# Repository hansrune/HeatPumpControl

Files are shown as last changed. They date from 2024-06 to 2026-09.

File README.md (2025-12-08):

# Generic ESP32 C3/C6 board with IR blaster, serial port, i2c, 1-wire and more

A small DYI generic mini IO based on ESP32C3 or ESP32C6 from Xiaomi SeeedStudio. This board has an IR blaster, IR receiver, and serial port with a simple 5V - 3.3V level shifter suitable for Mitsubishi CN105 port (similar for any RS-232 interfaces) . Other ESP32 pins are available with pin headers for I2C, 1-wire, and other general purposes

This board is tested with ESPhome and ESPEasy [firmware](#firmwares) (build instructions below), and is easily used with home automation systems that support MQTT auto discovery, the native Home Assistant API, and the many [controllers that ESPEasy supports](https://espeasy.readthedocs.io/en/latest/Controller/_Controller.html)

A [3D printed box](#./FreeCAD/) STL files and  the FreeCAD design is also available

**PLEASE NOTE**: Use at your own risk. The ESPhome firmwares are unofficial and reverse-engineered Mitsubishi protocol based on the [Swicago library](https://github.com/SwiCago/HeatPump). The authors and contributors have extensively tested this firmware. Please note that not all units support every feature. If you need an officially supported method to remotely control your Mitsubishi device via WiFi, a commercial solution is available [here](https://www.mitsubishi-electric.co.nz/wifi/)

## Introduction

This small IO board was made to easily fit inside a small DYI box, a heat pump or other.

For Mitsubushi heat pumps, the CN105 connector is used for serial port communications and for power supply.

Some of the main features and benefits

- **Serial port with simple level shifter for 5V serial ports**
    - The CN105 port of Mitsubishi ports can be used - and will then also provide the power supply for the board
- **An IR blaster circuit**
    - Some features / command packets are easier to find from a native IR receiver
- **I2C and/or 1-wire**
- **Other GPIO ports**
- **WiFi based**
    - This is almost a must have for most home automation systems
    - OTA support
    - Configuration backup, restore and bulk updates.
- **Firmware of your choise**
    - ESPEasy with Domoticz over http. Device creation uses virtual sensors
    - ESPEasy with Domoticz and Home Assistant via MQTT. Device creation uses a MQTT configuration text file.
    - ESPHome to Home Assistant via MQTT and auto discovery
    - ESPHome to Domoticz via MQTT and auto discovery
    - ... and as the hardware supports using both Arduino and ESP-IF development kits, almost any other firmware can be created.
- **3D printed enclosure**
    - [FreeCAD](./FreeCAD) and `.stl` files provided
- **Seed Studio XIAO ESP32C3**
    - This device is well shielded and comes with an externam IPX antenna connector
    - FCC and CE regulations approved

### Heat pump wiring

The wiring for a Mistubishi heat pump:

<p align="center">
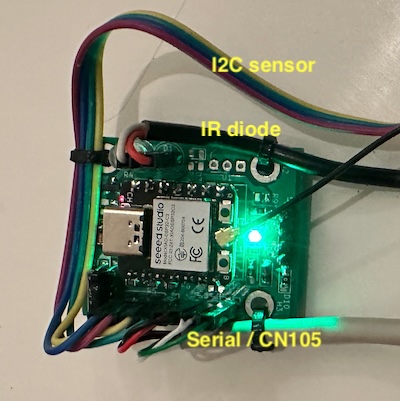
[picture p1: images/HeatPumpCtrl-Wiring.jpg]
    
</p>

A visible LED can be used in series with the IR LED - just in case you want to see the activity

The serial port - CN105 - on our Mitsubishi heat pumps:

<p align="center">
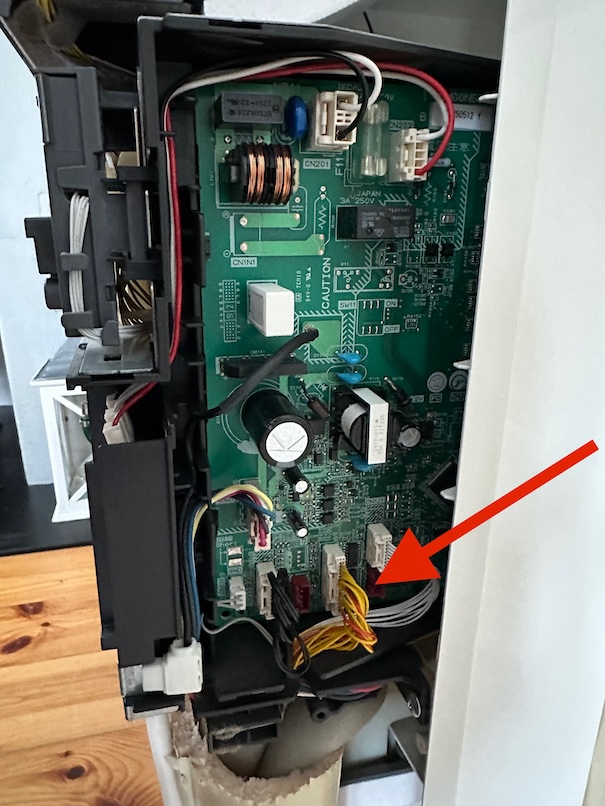
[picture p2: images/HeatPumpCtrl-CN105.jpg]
    
</p>

The IR sender led fits inside the receiver housing:

<p align="center">
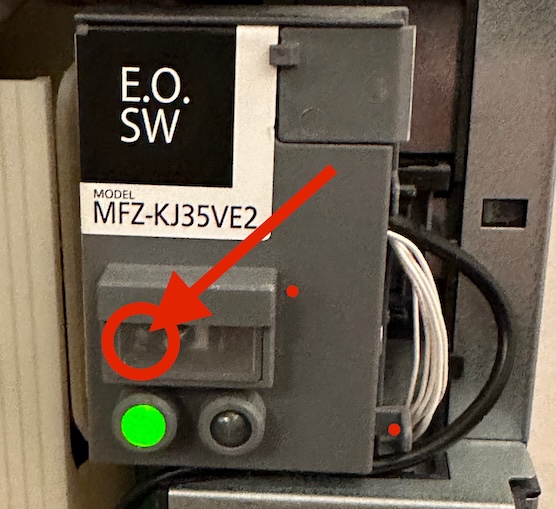
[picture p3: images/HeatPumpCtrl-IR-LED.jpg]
    
</p>

And the device including enclosure is tiny, i.e. easy to find room for inside the heat pump:

<p align="center">
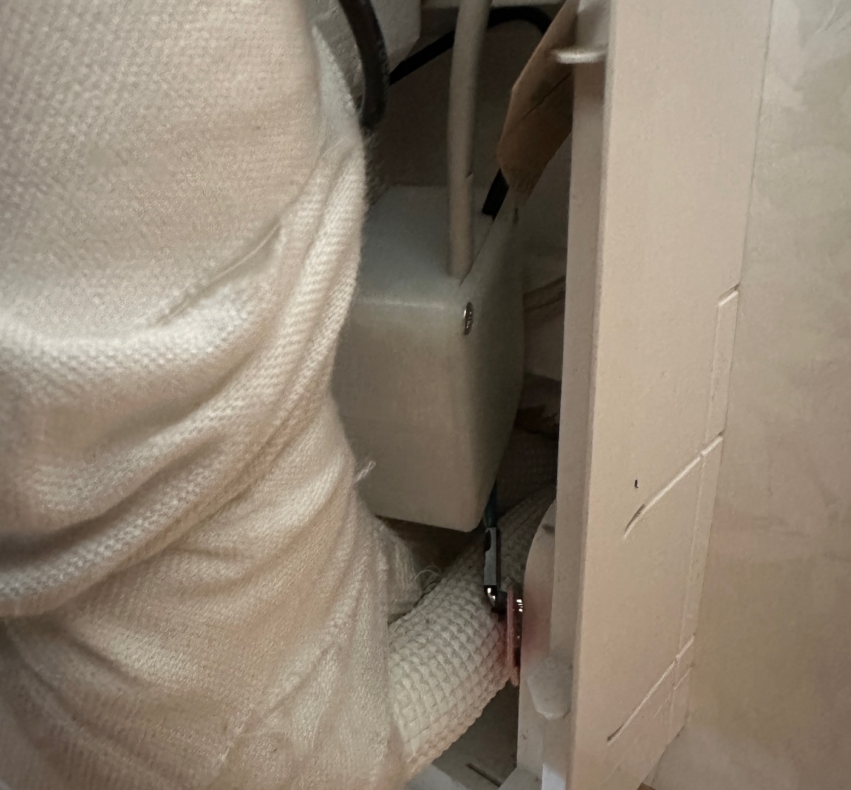
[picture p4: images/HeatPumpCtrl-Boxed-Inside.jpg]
    
</p>

### Wiring for other purposes

The same PCB can be used for many other purposes. Here is for a firmware build test with CO2 sensor, I2C temp/humid and light, PIR sensor and a 1-wire temp sensor

<p align="center">
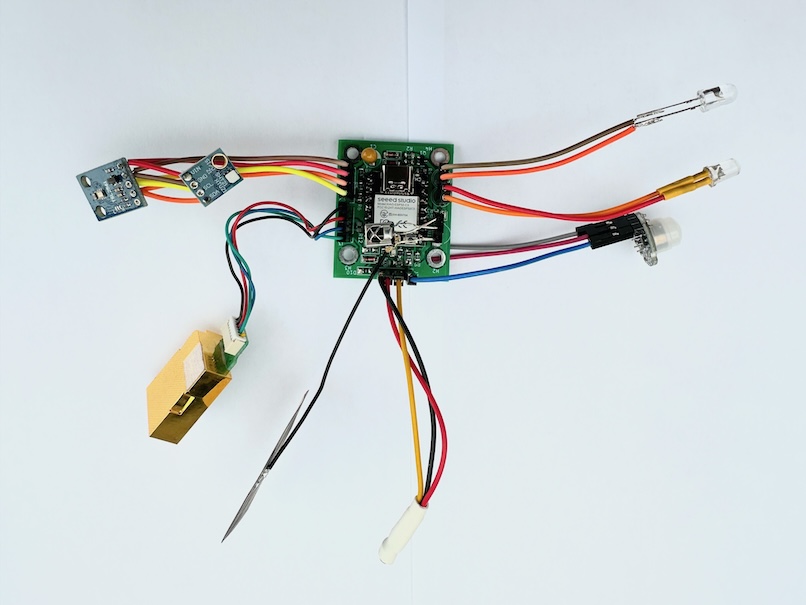
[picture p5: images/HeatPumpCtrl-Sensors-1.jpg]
    
</p>

## Implementation and design

The schematic diagram is [available here](KiCad/HeatPumpControl-schema-2.0.pdf). The [KiCad EDA](https://www.kicad.org/) project is in the [same folder](./KiCad)

## GPIO pin usage

| PIN | Capabilty | Function |
|---|---|---|
| GPIO2 | Pulled up | N/A |
| GPIO3/A1 | Generic IO | On IR receiver pin header |
| GPIO4 | Actice high out | IR sender |
| GPIO5 | Generic IO | Pull-up possible |
| GPIO6 | I2C | SDA |
| GPIO7 | I2C | SCL |
| GPIO9 | Active low out | Internal status LED |
| GPIO10 | Generic IO | Pull-up possible |
| GPIO20 | RX | Serial to heatpump TX |
| GPIO21 | TX | Serial to heatpump RX |

## Hardware - getting started

This project uses my [KiCad-lib-ESP32 repository](https://github.com/hansrune/KiCad-lib-ESP32.git) as a [git submodule](https://www.git-scm.com/book/en/v2/Git-Tools-Submodules). To check this out, use the following:

```bash
git clone --recurse-submodules https://github.com/hansrune/HeatPumpControl.git 
```

### Materials used

This project uses the [Seed Studio XIAO ESP32C3 RISC-V module](https://www.seeedstudio.com/Seeed-XIAO-ESP32C3-p-5431.html). This tiny device has proven to be more reliable than most ESP8266 modules. This module also comes with an IPX connector for an external antenna, and is delivered with a simple external antenna for good range.

5V power can be supplied over USB-C or the serial port pin headers

For more information, use [this KiCad BOM](KiCad/HeatPumpControl-BOM.csv)

## Hardware assembly

Soldering a prototype by hand is possible if you have a steady hand and a small solder iron tip. A microscope is recommended to propely inspect the solder joints.

Recommend to do the SMD parts first, then other components.

## 3D printed enclosure

An enclosure made in [FreeCAD](https://www.freecad.org/) is available in [this folder](./FreeCAD). You may also just use the `.stl` files for your 3D printer slicer.

## Firmwares

### ESPHome

ESPHome firmware can be set up from [this ESPHome configuration repository](https://github.com/hansrune/esphome-config) using the `test_mitsubishi_hp.yaml` as a template

Follow the [README](https://github.com/hansrune/esphome-config) for instruction on what you will likely want to change.

By default, both the serial CN105 interface as well as the IR sender is set up in this firmware. You likely want just one of them.

In Home Assistant, there is this serial port / CN105 connected control

<p align="center">
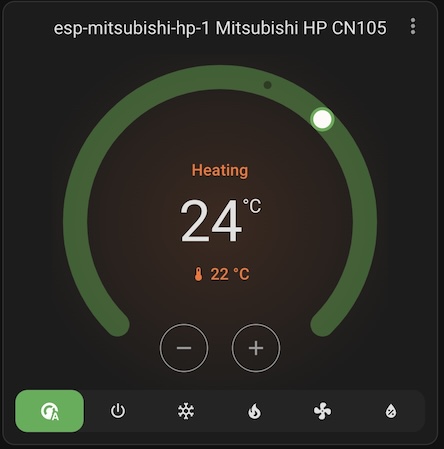
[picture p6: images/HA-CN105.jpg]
    
</p>

The IR blaster control:

<p align="center">
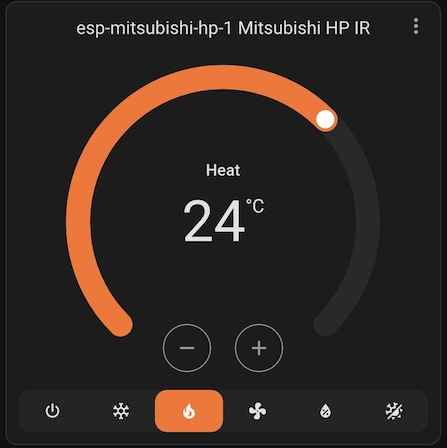
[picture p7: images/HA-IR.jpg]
    
</p

And the diagnostics / device details:

<p align="center">
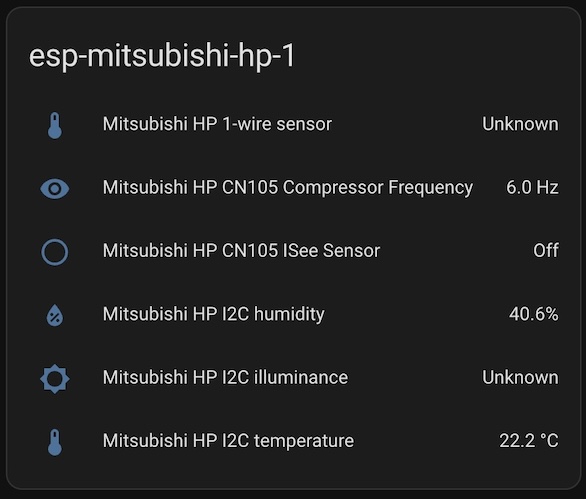
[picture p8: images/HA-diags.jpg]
    
</p>

No 1-wire and lux sensor connected in this case

### ESPEasy

ESPEasy can be used with a number of different controllers / home automation systms. A custom firmware build description is [available here](https://github.com/hansrune/ESPEasy-custom/blob/builds/custom/mega-20240822-1/README-custombuilds.md)

ESPEasy requires many settings. For configuration settings and rule files, you can upload the files from [this page](./ESPEasy/) as a starting point. Please make sure to change name, unit number, controller IP addresses, NTP, syslog host and latitude/longitude. This configuration uses both a MQTT controller and a Domoticz controller. Change to what you need.

### Alternatve firmware

You may be interested in looking at alternative firmwares such as [this one](https://github.com/echavet/MitsubishiCN105ESPHome)

## Known bugs

The version 2.0 PCB has some flaws that fairly easy to work around:

- The NPN-tranistor need to be mounted upside down
- The copper fill grounding is missing for the IR receiver GND pin. An added wire is needed if you use it

## License

This project is licensed under the [GNU General Public License v3.0](GNU-LICENSE-V3.txt) for the software, [CERN-OHL-W](OHL-LICENSE.txt) for the hardware, and [CC BY-SA](CC-BY-SA-LICENCE.txt) for the documentation and ideas.

<p align="center">
    
</p>

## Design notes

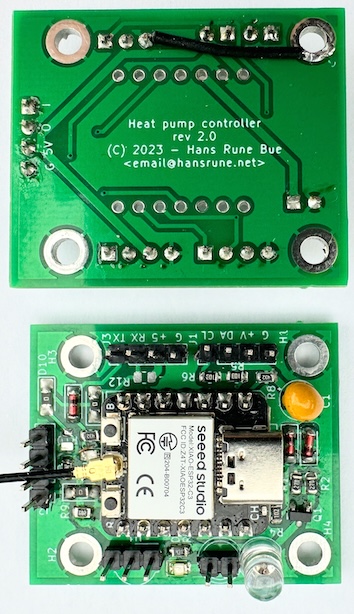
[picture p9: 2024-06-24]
images/HeatPumpCtrl-PCB-Mounts.jpg

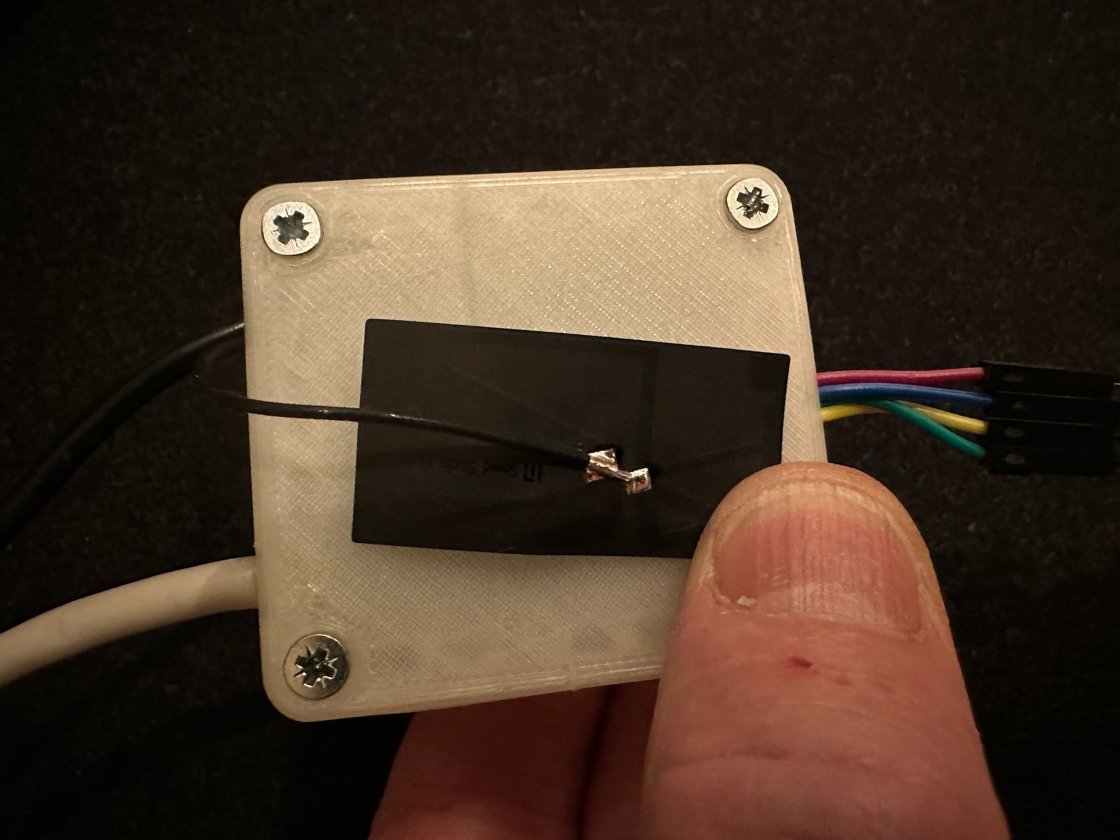
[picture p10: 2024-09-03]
images/HeatPumpCtrl-Enclosure.jpeg

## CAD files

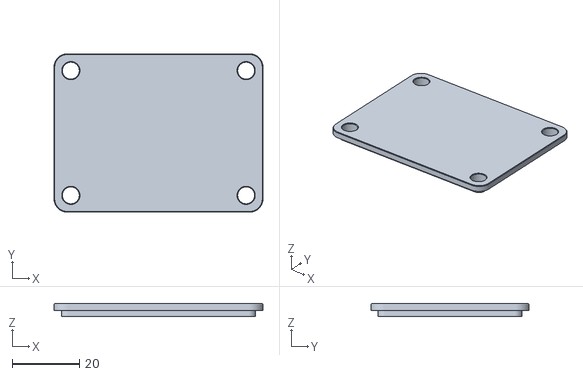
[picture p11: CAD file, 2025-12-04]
FreeCAD/HeatPumpControl-Lid-4.stl
62.0 x 47.0 x 3.80

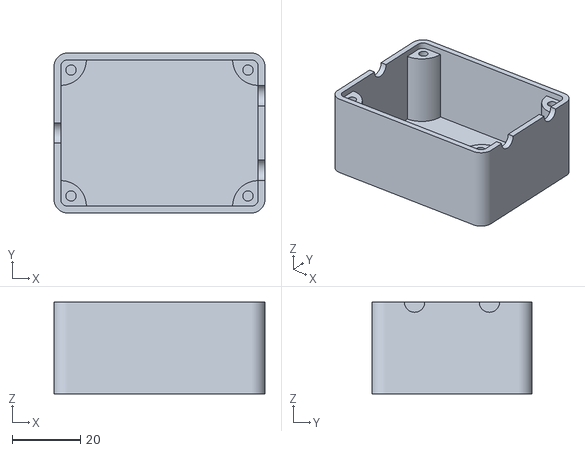
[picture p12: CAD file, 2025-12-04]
FreeCAD/HeatPumpControl-Body-4.stl
62.0 x 47.0 x 27.0

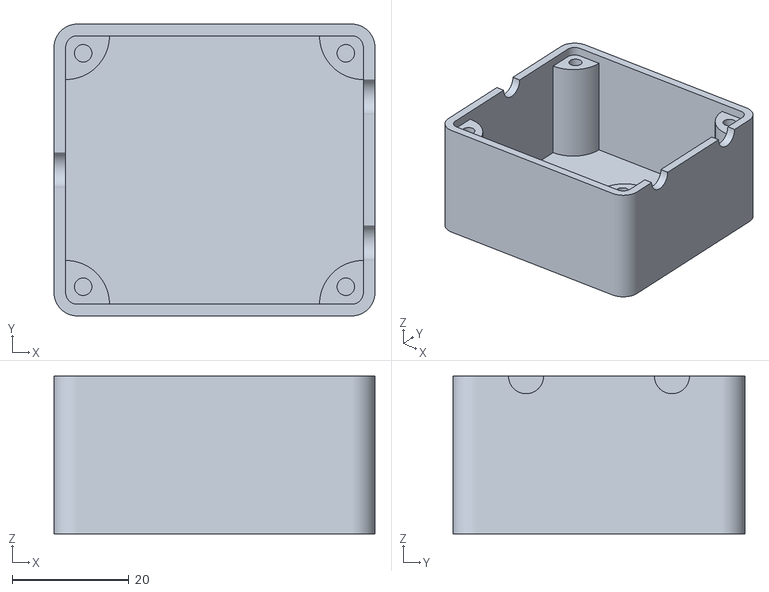
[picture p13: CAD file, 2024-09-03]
FreeCAD/HeatPumpControl-Body.stl
55.0 x 50.0 x 27.0

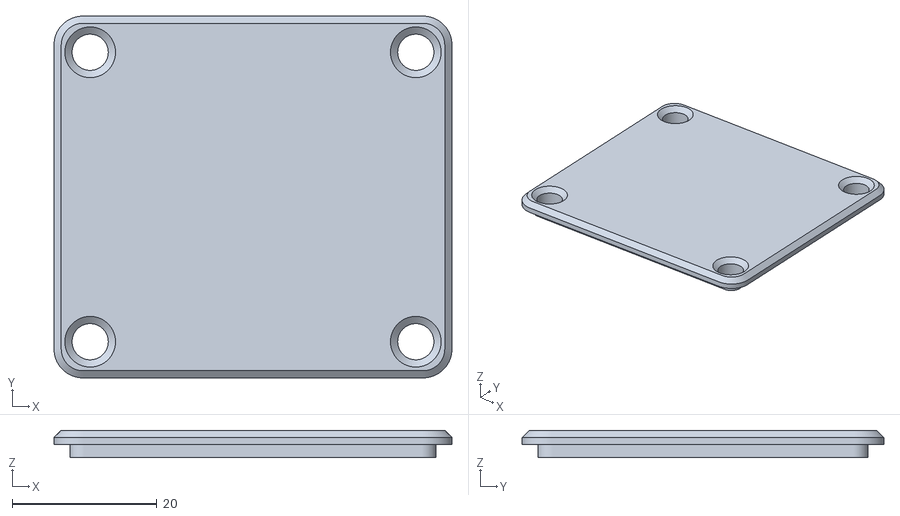
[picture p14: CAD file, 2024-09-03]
FreeCAD/HeatPumpControl-Lid.stl
55.0 x 50.0 x 3.80

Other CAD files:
FreeCAD/HeatPumpControl.FCStd

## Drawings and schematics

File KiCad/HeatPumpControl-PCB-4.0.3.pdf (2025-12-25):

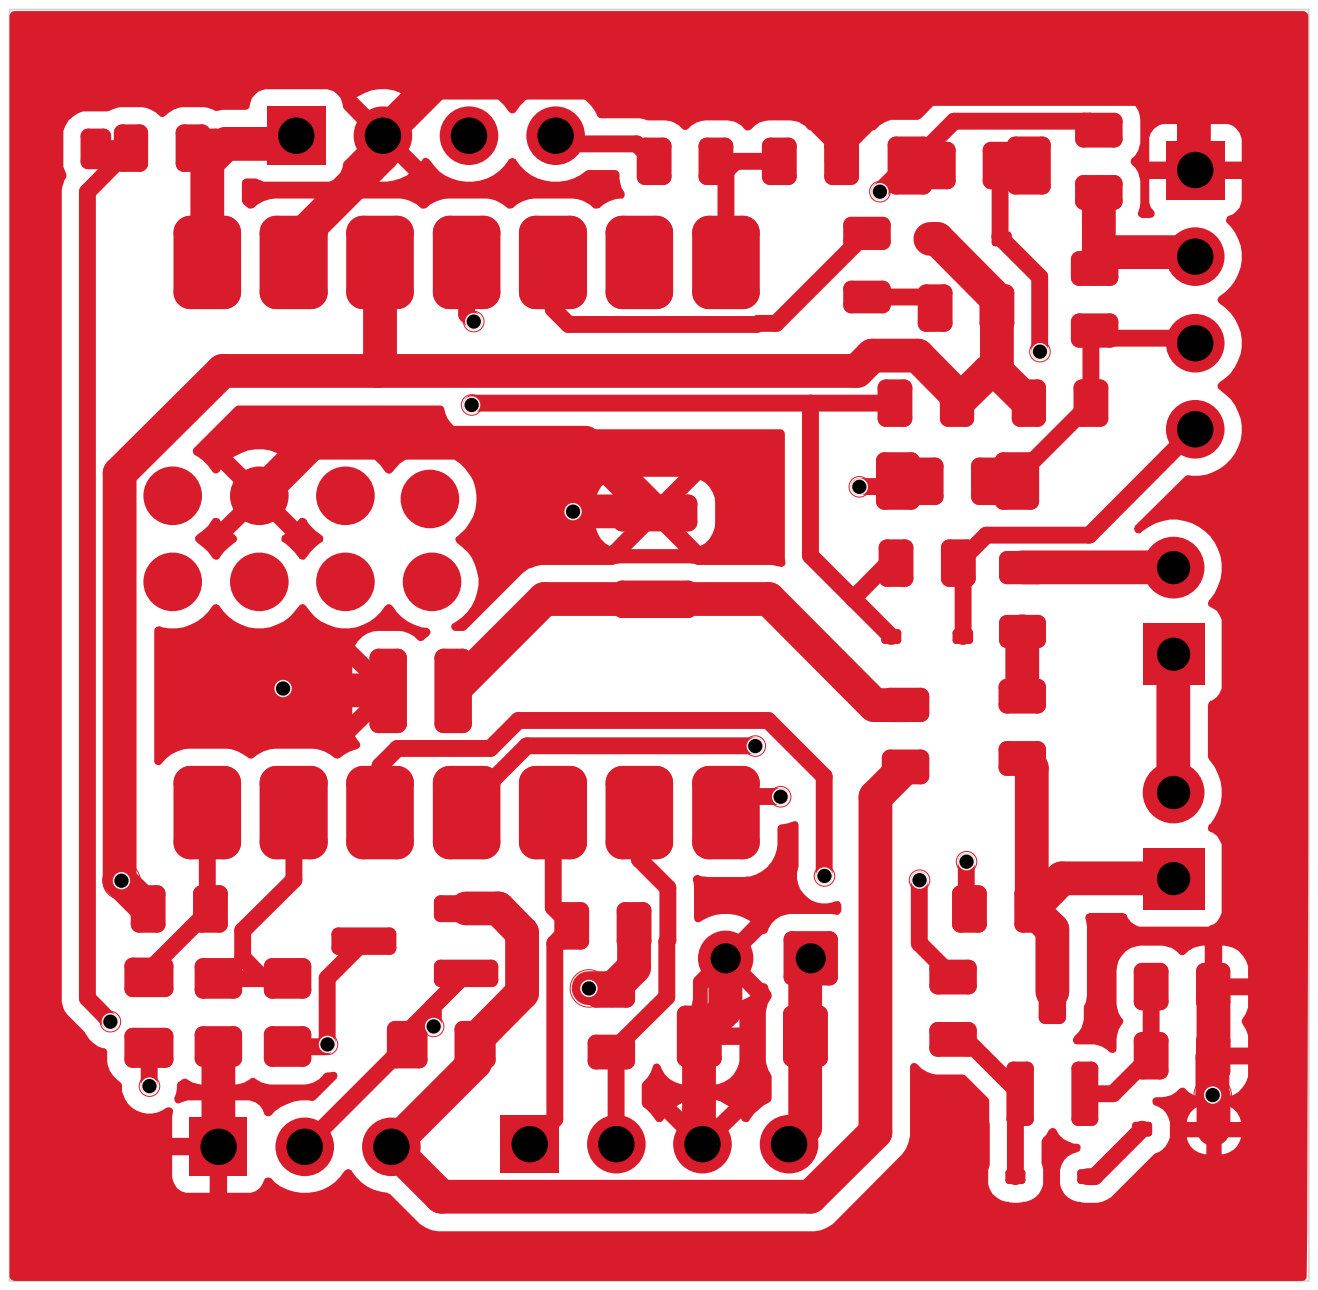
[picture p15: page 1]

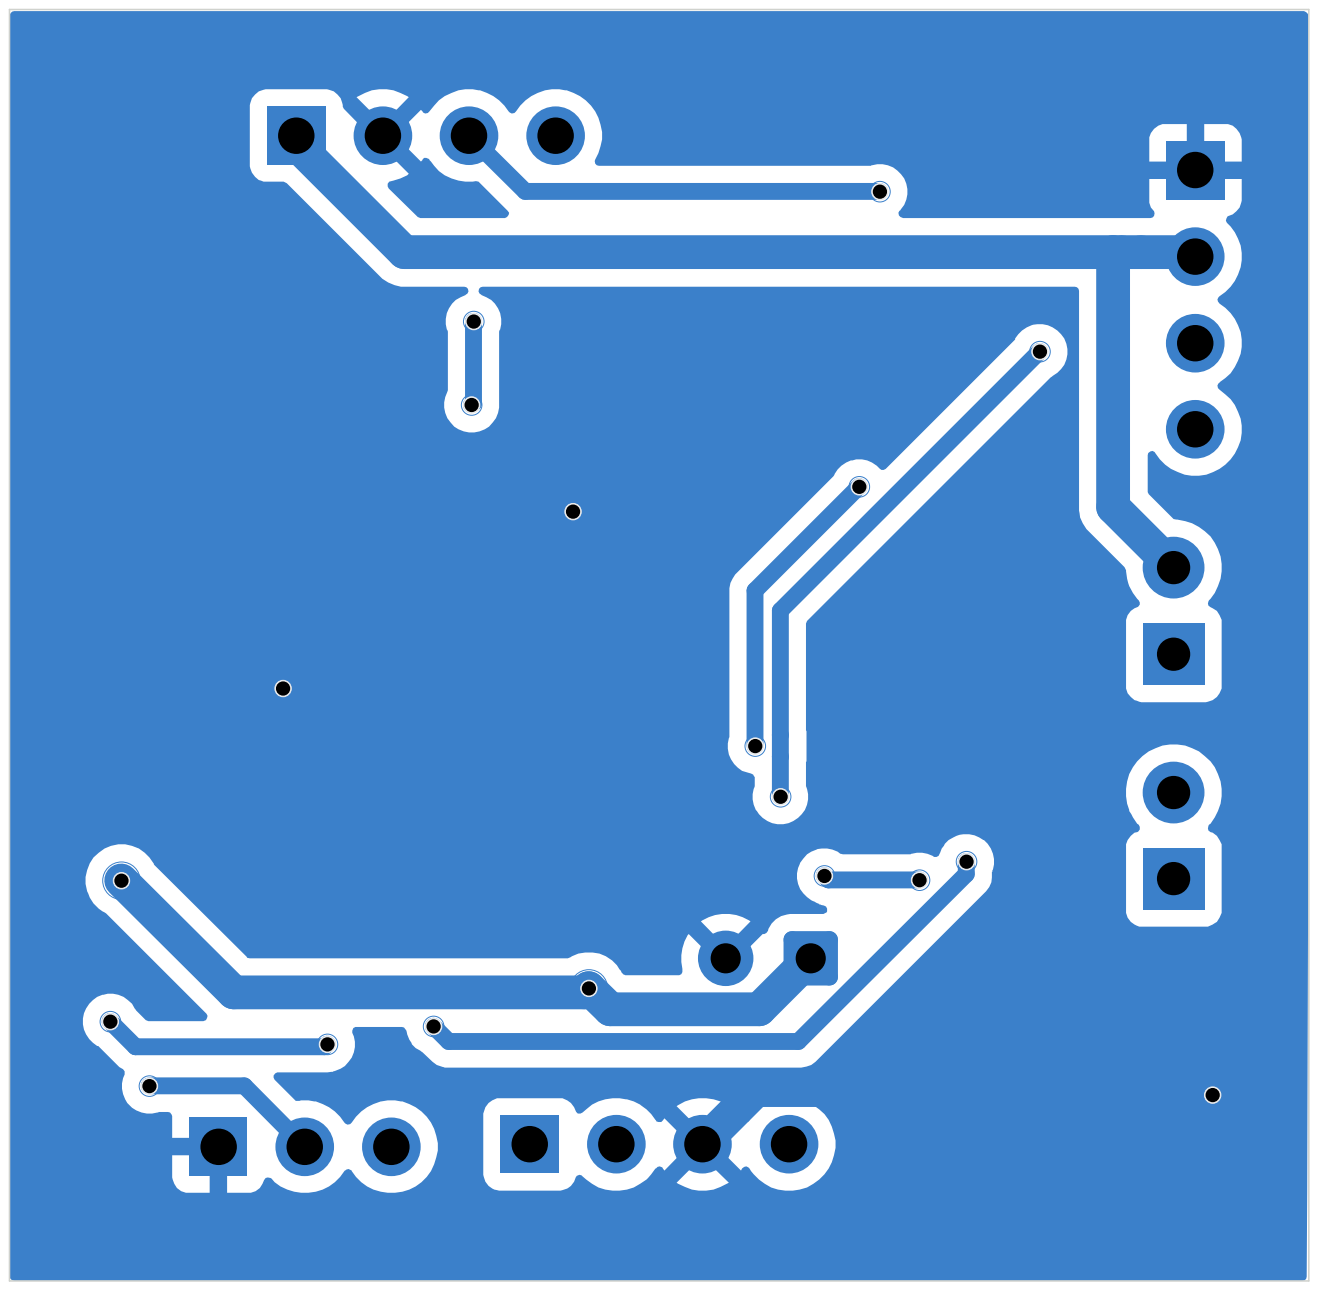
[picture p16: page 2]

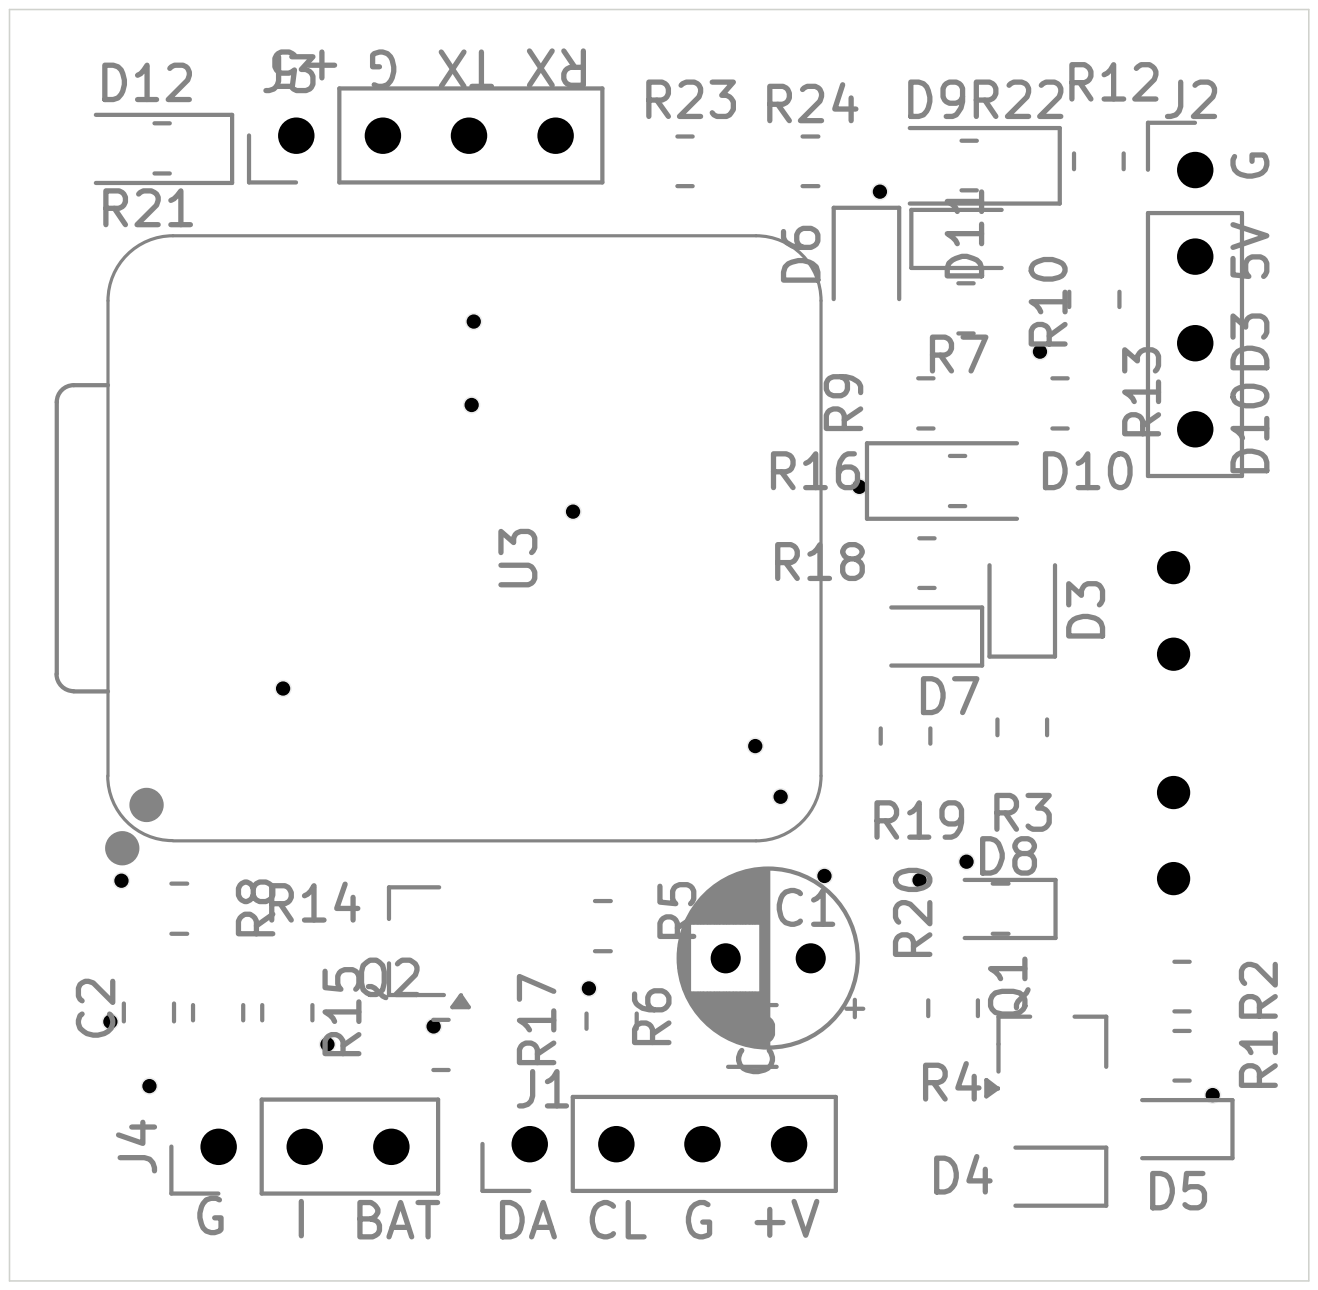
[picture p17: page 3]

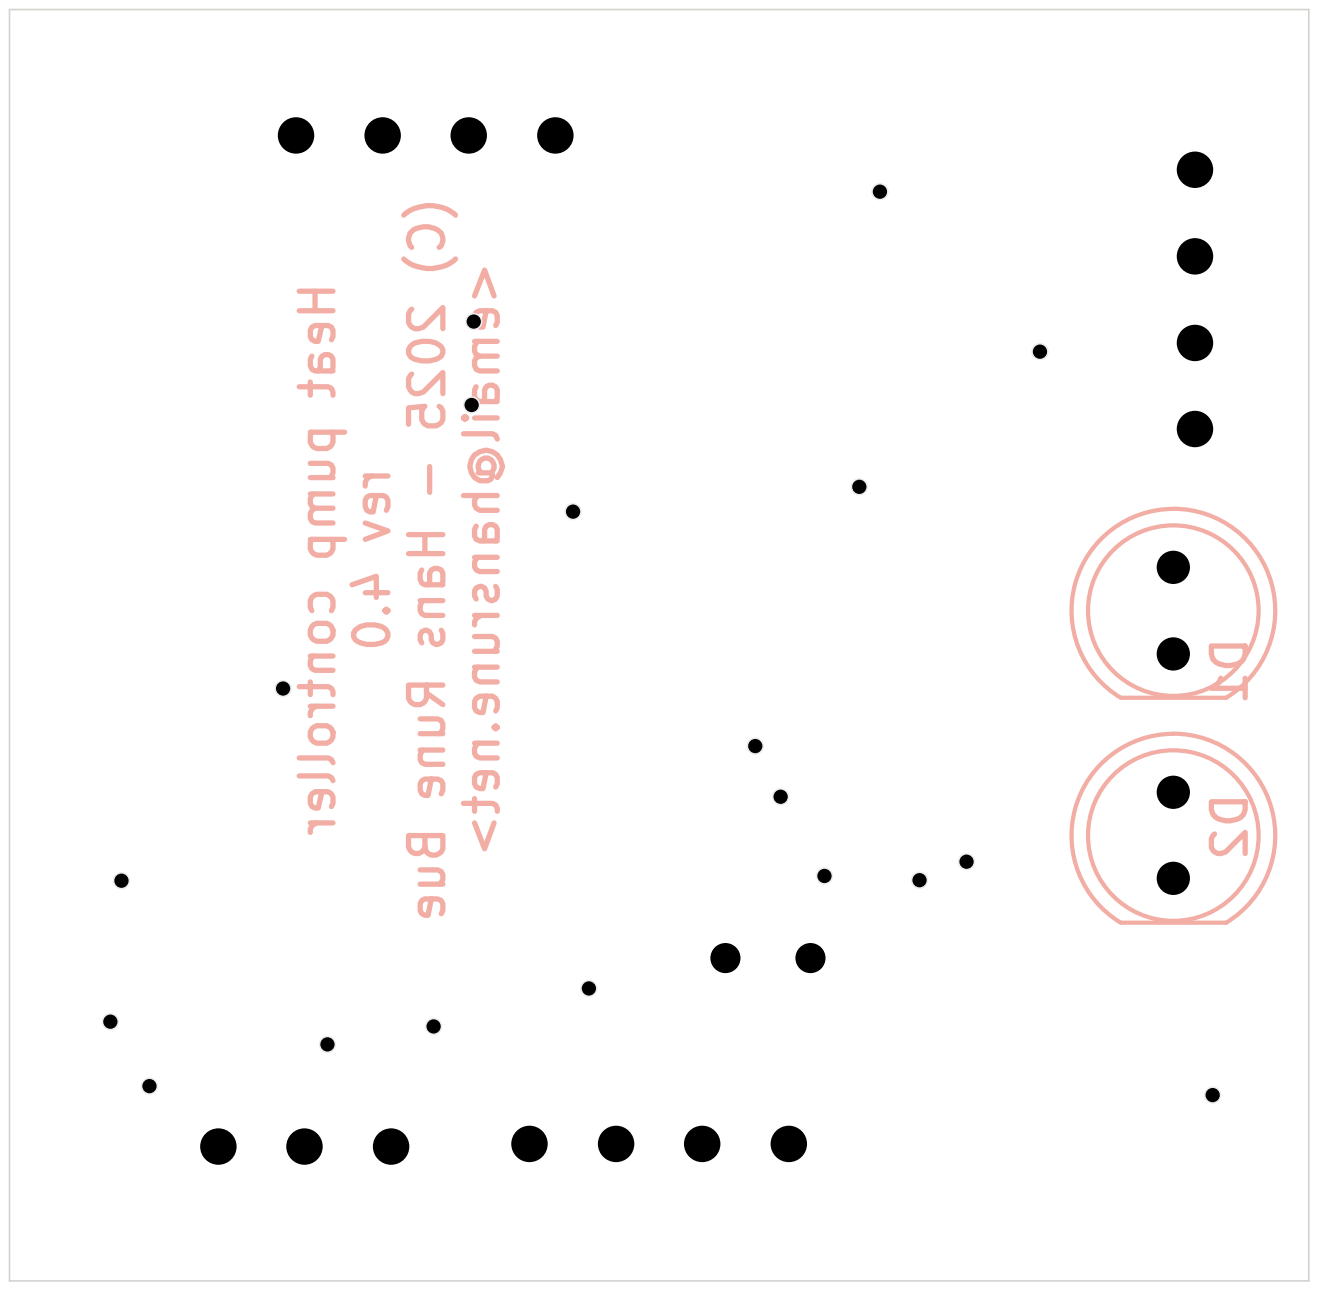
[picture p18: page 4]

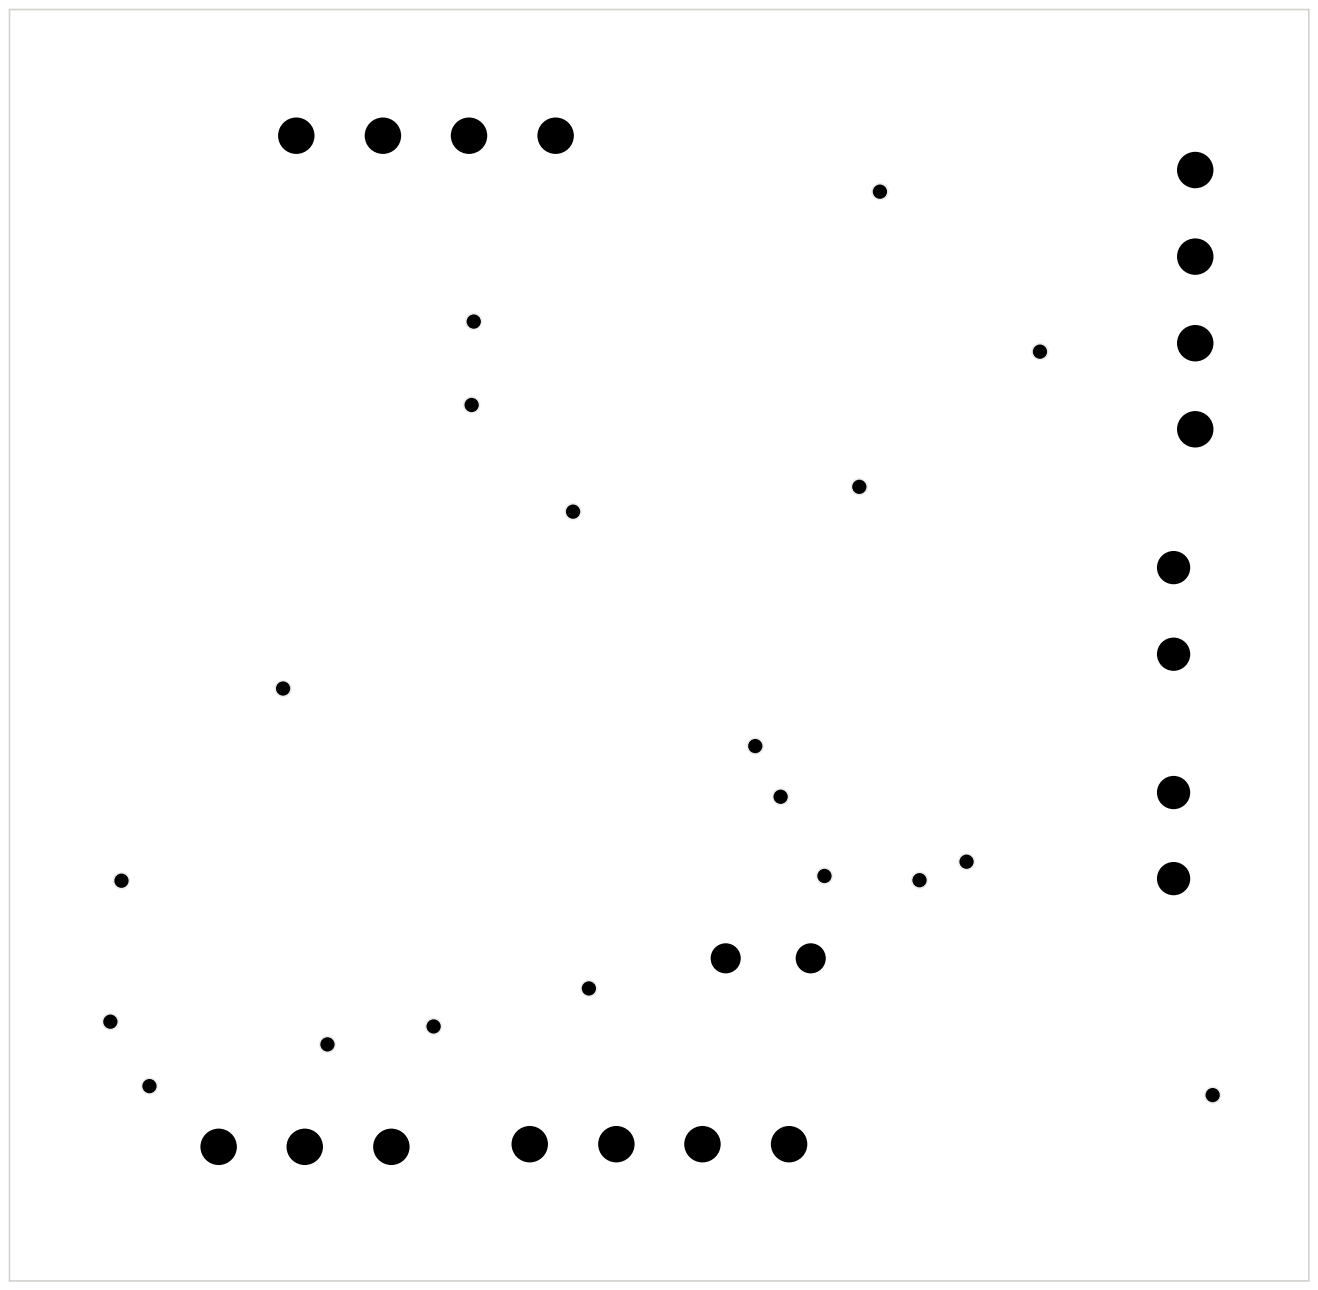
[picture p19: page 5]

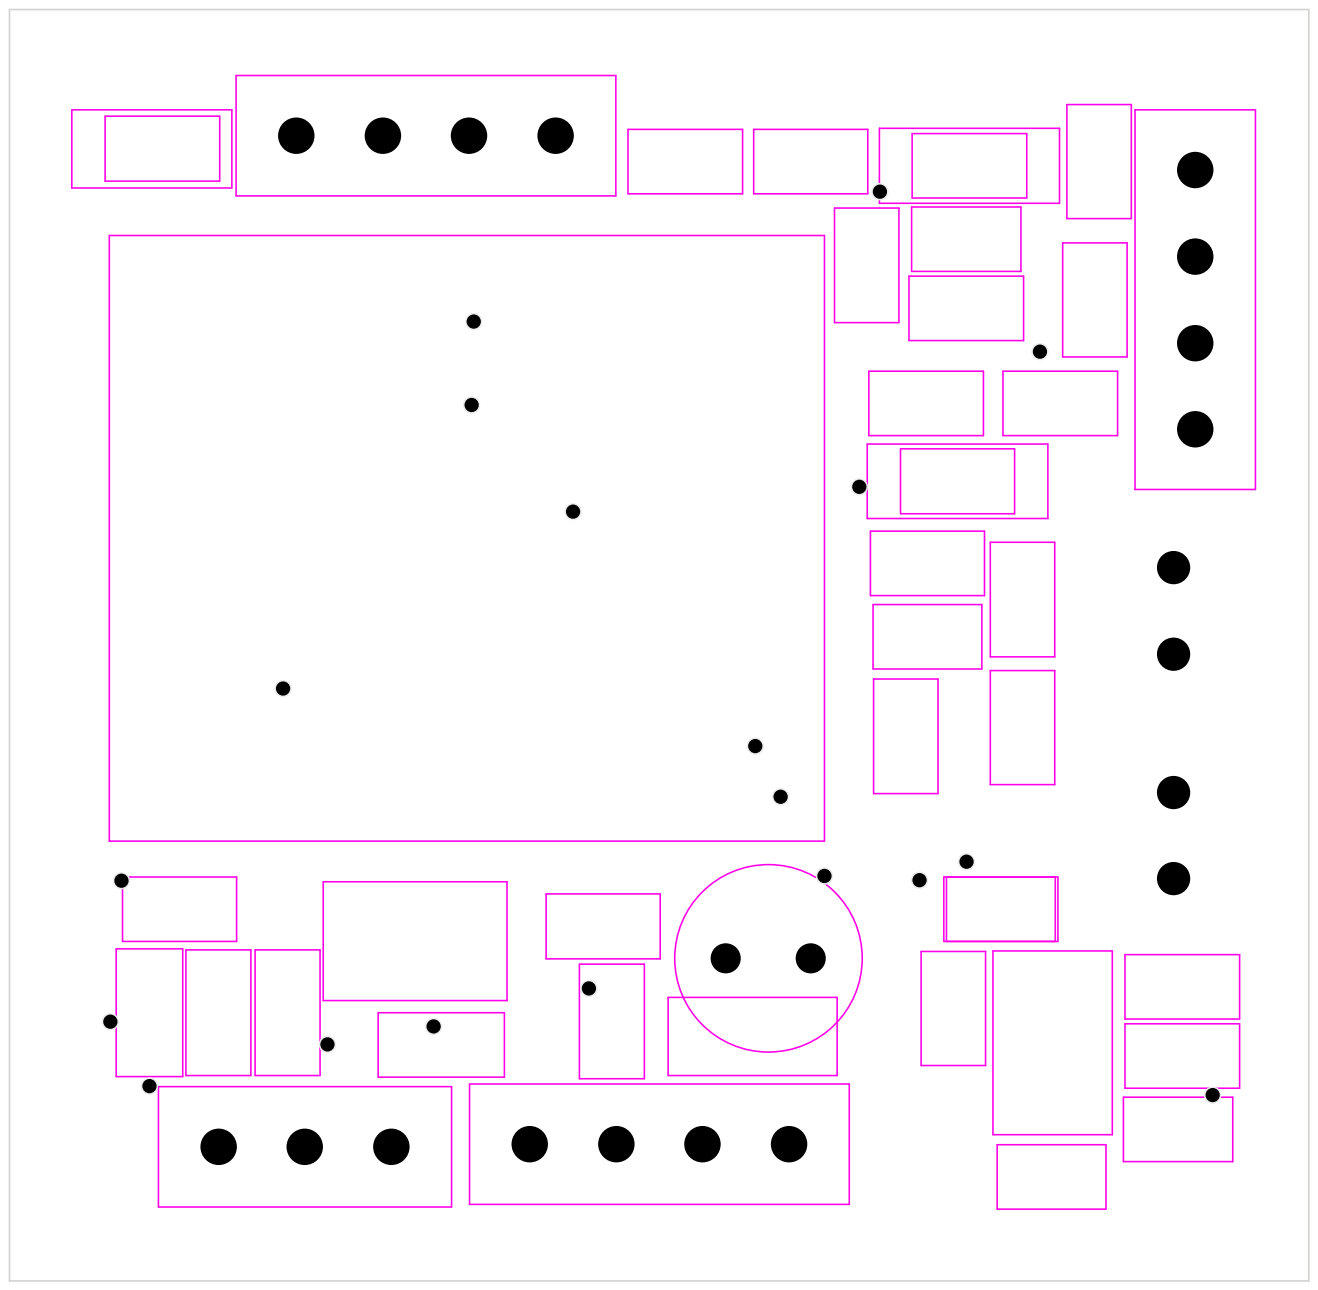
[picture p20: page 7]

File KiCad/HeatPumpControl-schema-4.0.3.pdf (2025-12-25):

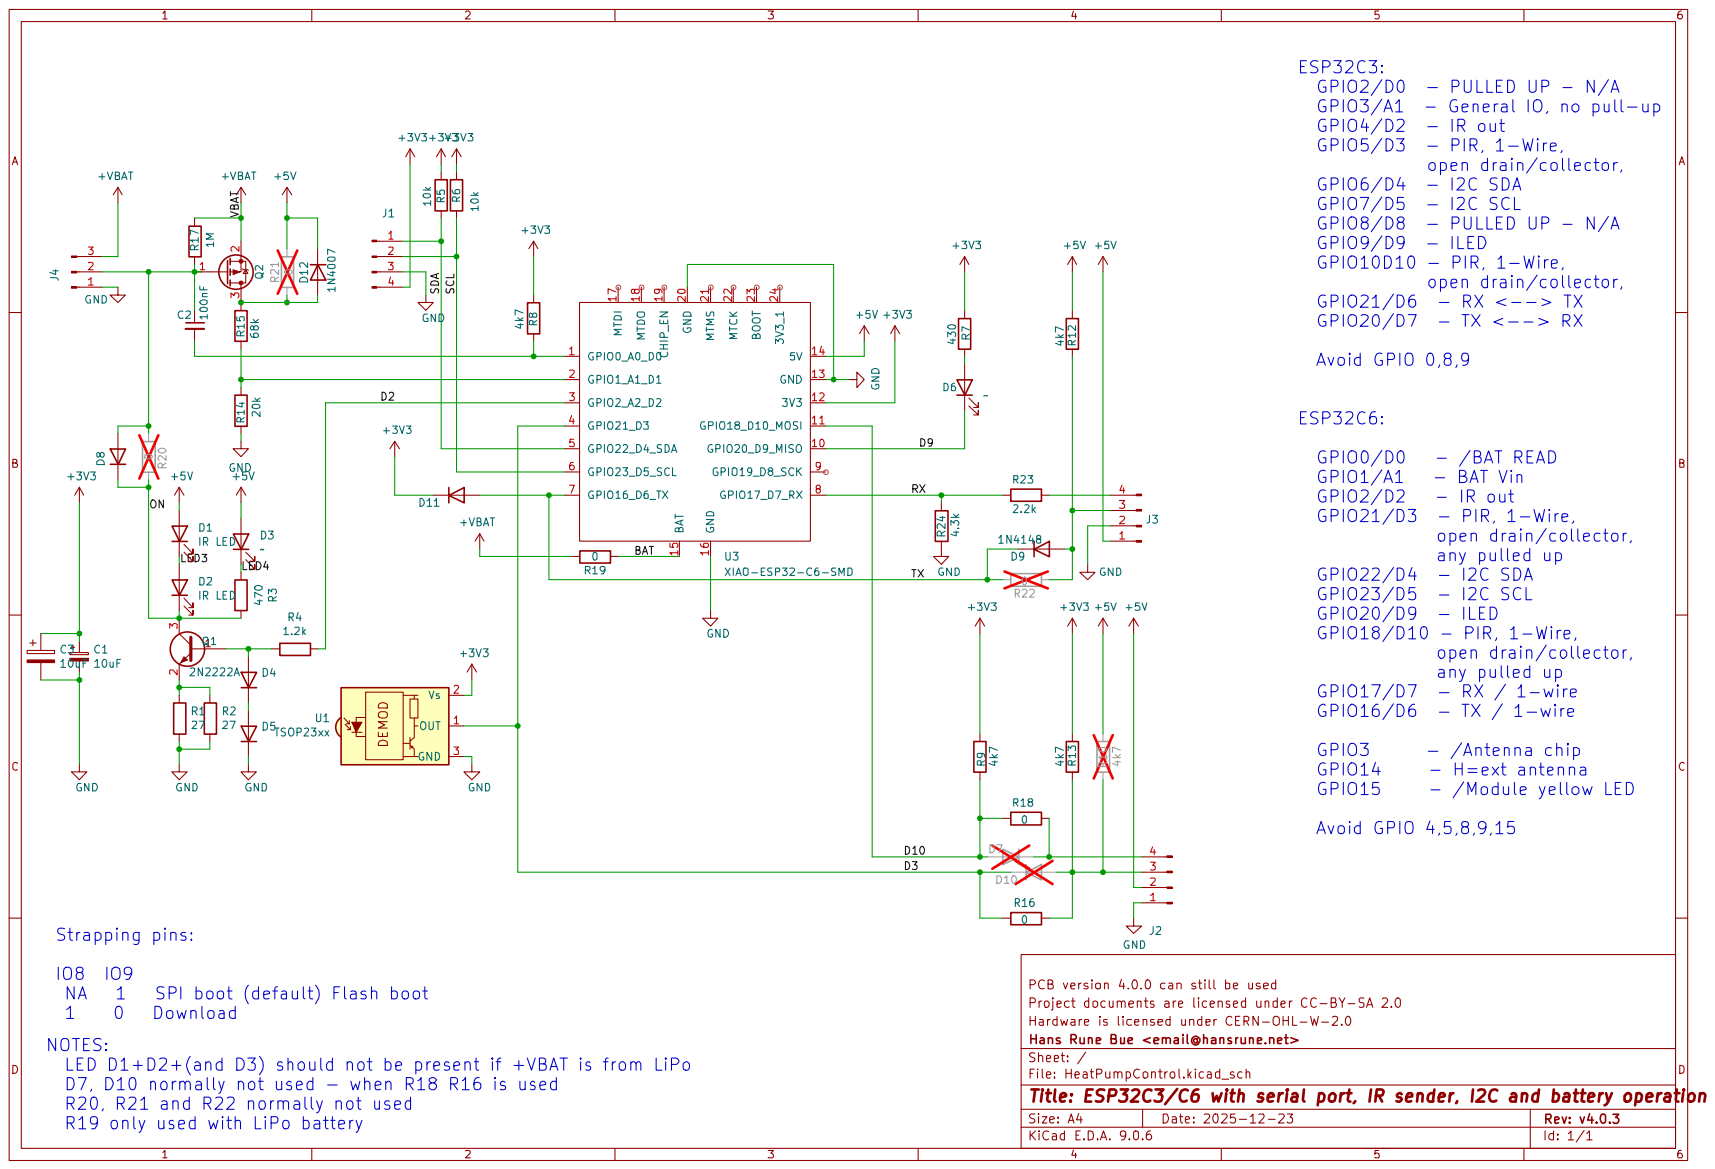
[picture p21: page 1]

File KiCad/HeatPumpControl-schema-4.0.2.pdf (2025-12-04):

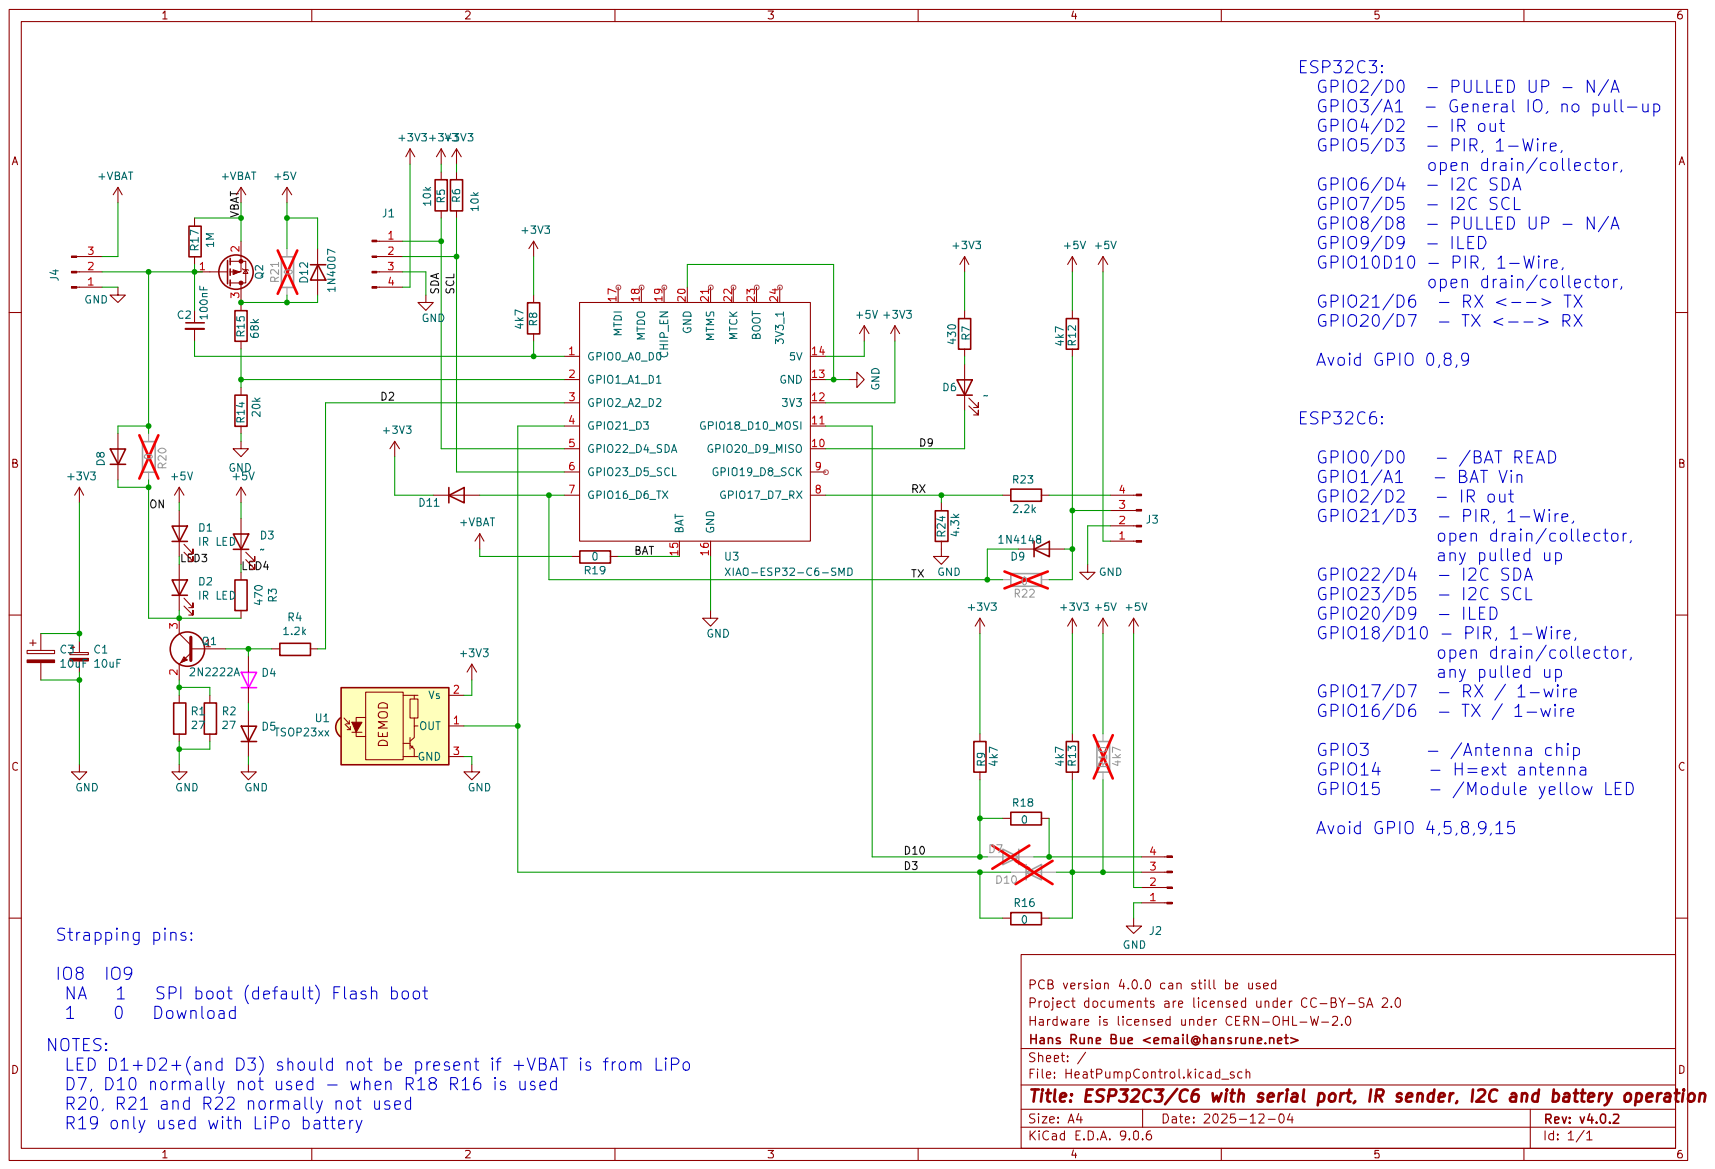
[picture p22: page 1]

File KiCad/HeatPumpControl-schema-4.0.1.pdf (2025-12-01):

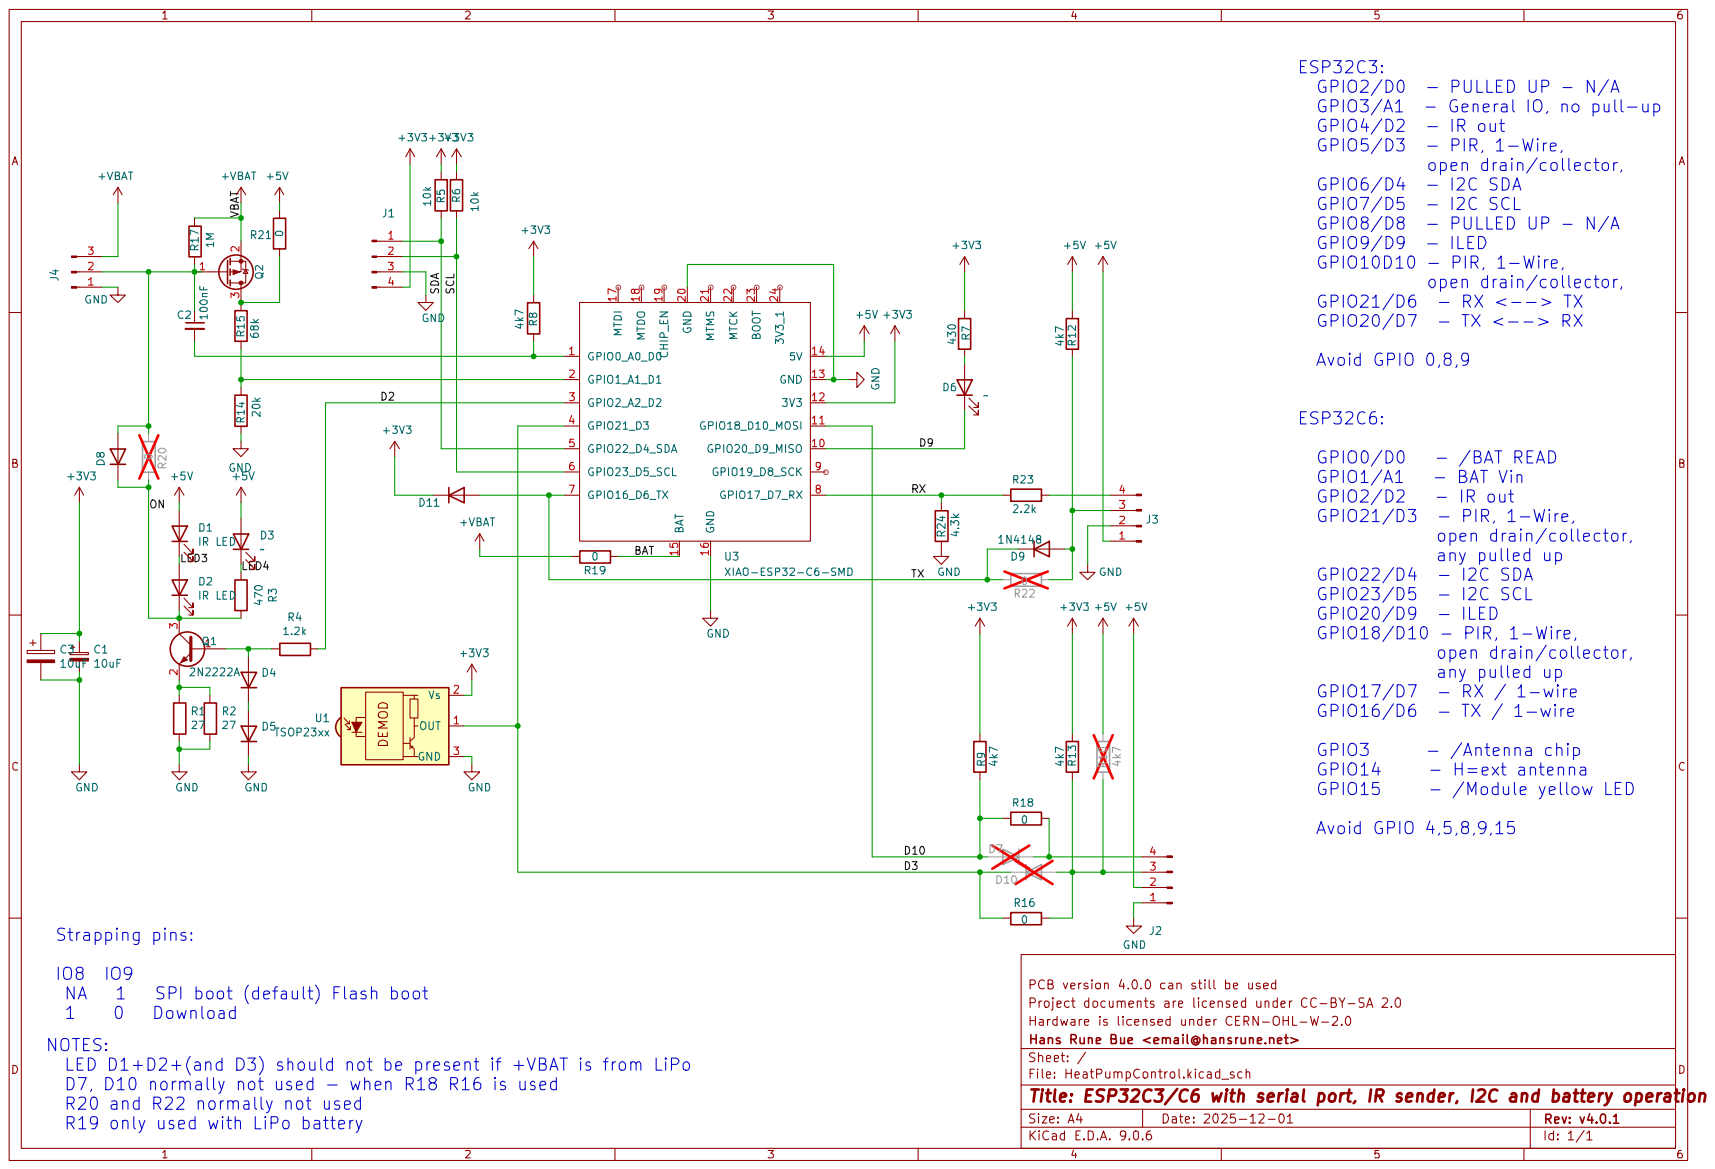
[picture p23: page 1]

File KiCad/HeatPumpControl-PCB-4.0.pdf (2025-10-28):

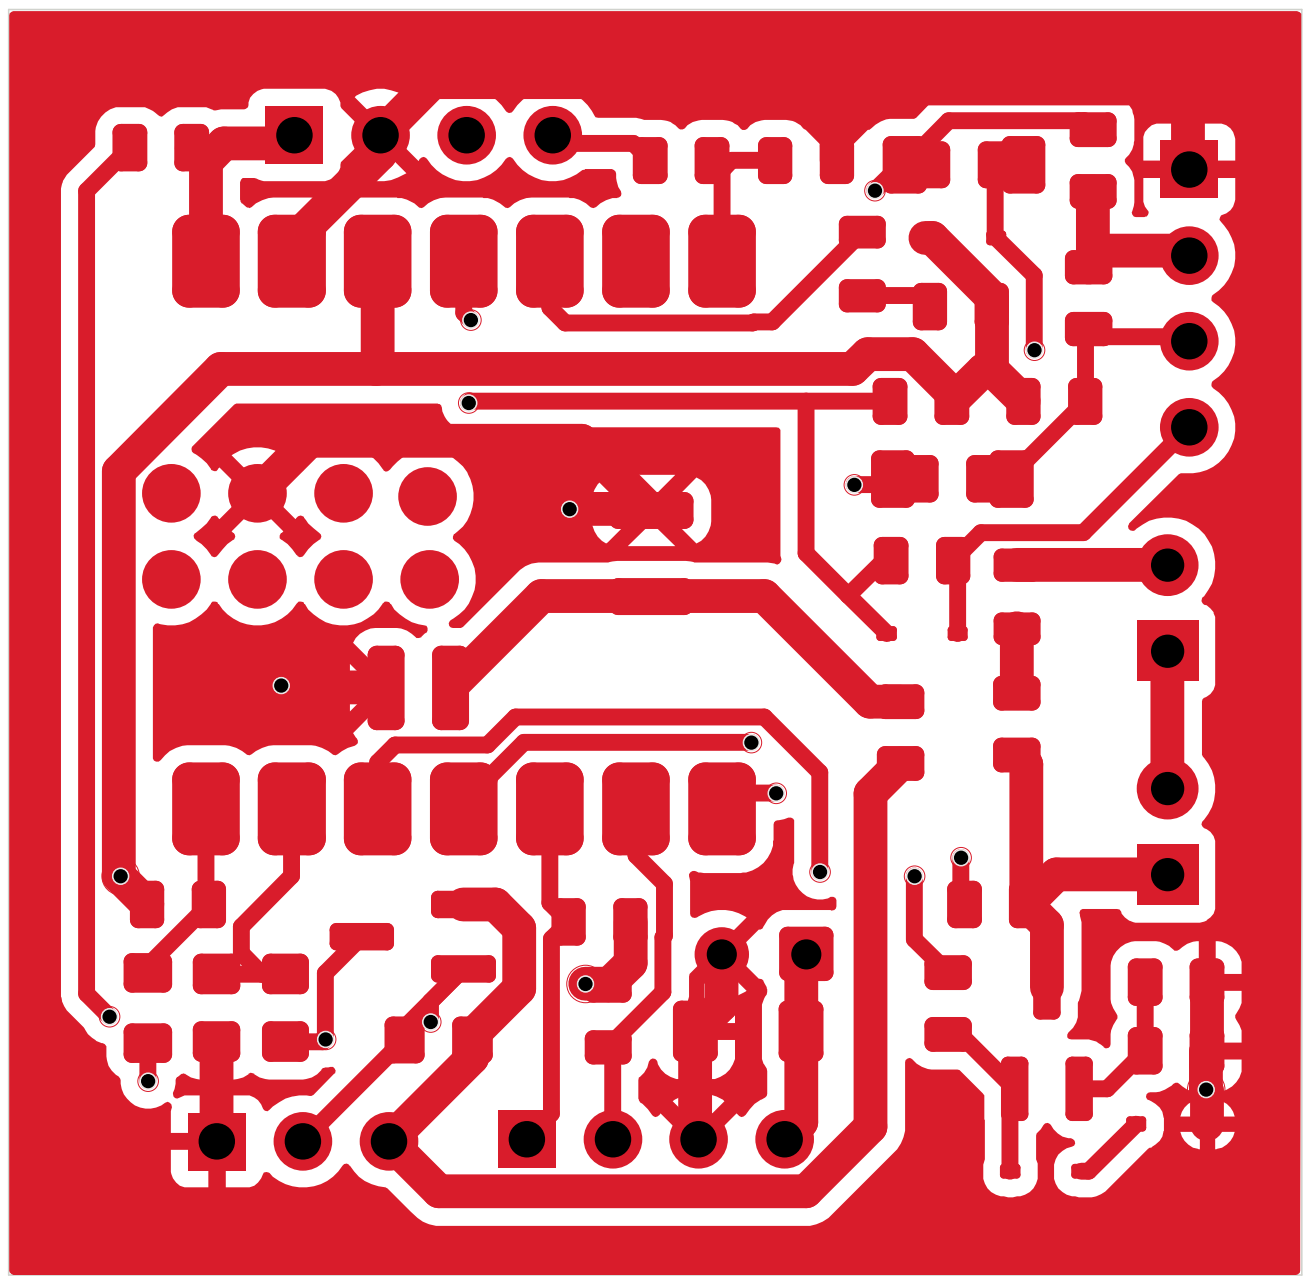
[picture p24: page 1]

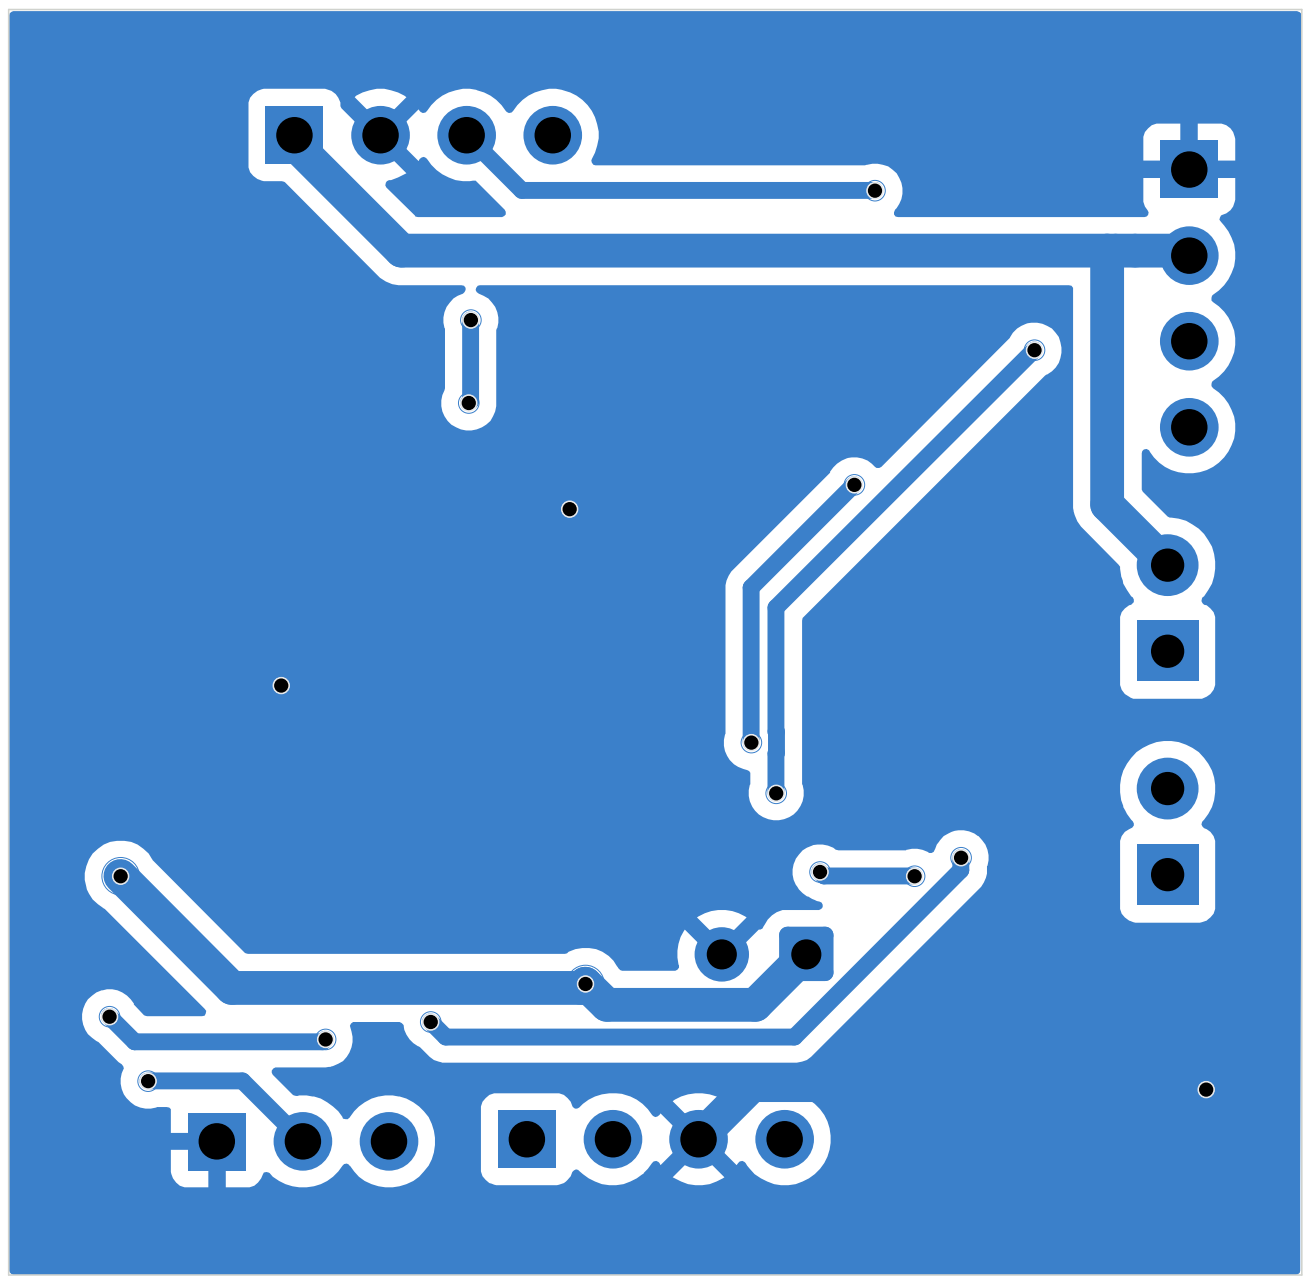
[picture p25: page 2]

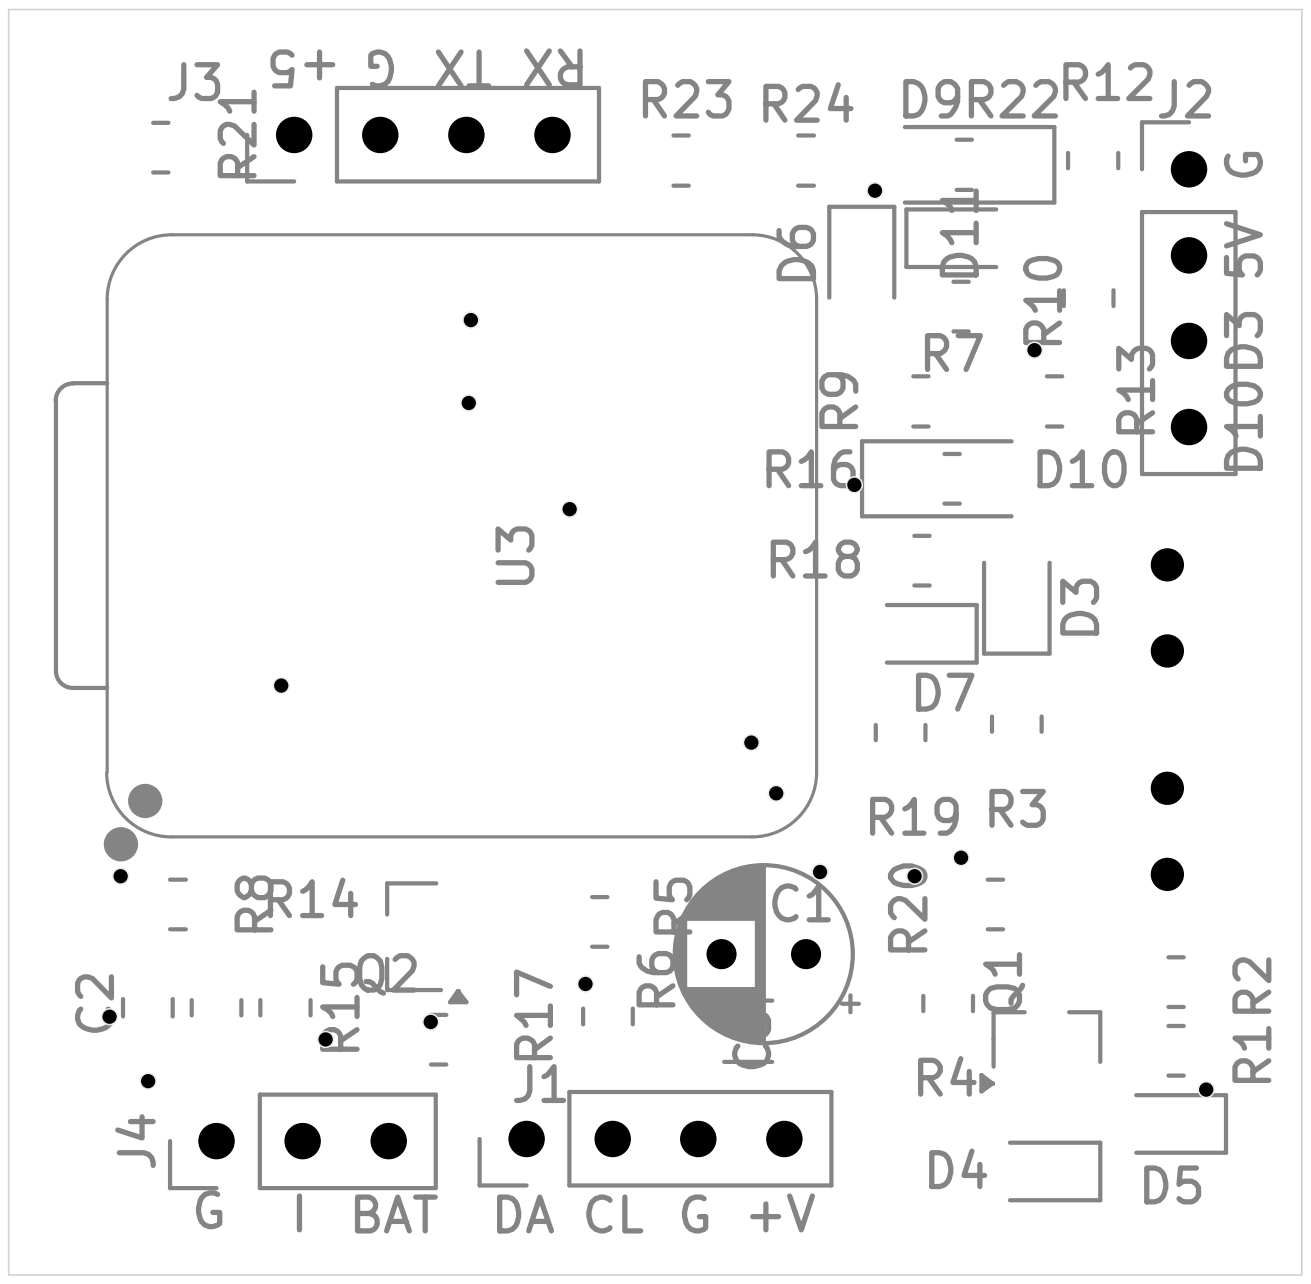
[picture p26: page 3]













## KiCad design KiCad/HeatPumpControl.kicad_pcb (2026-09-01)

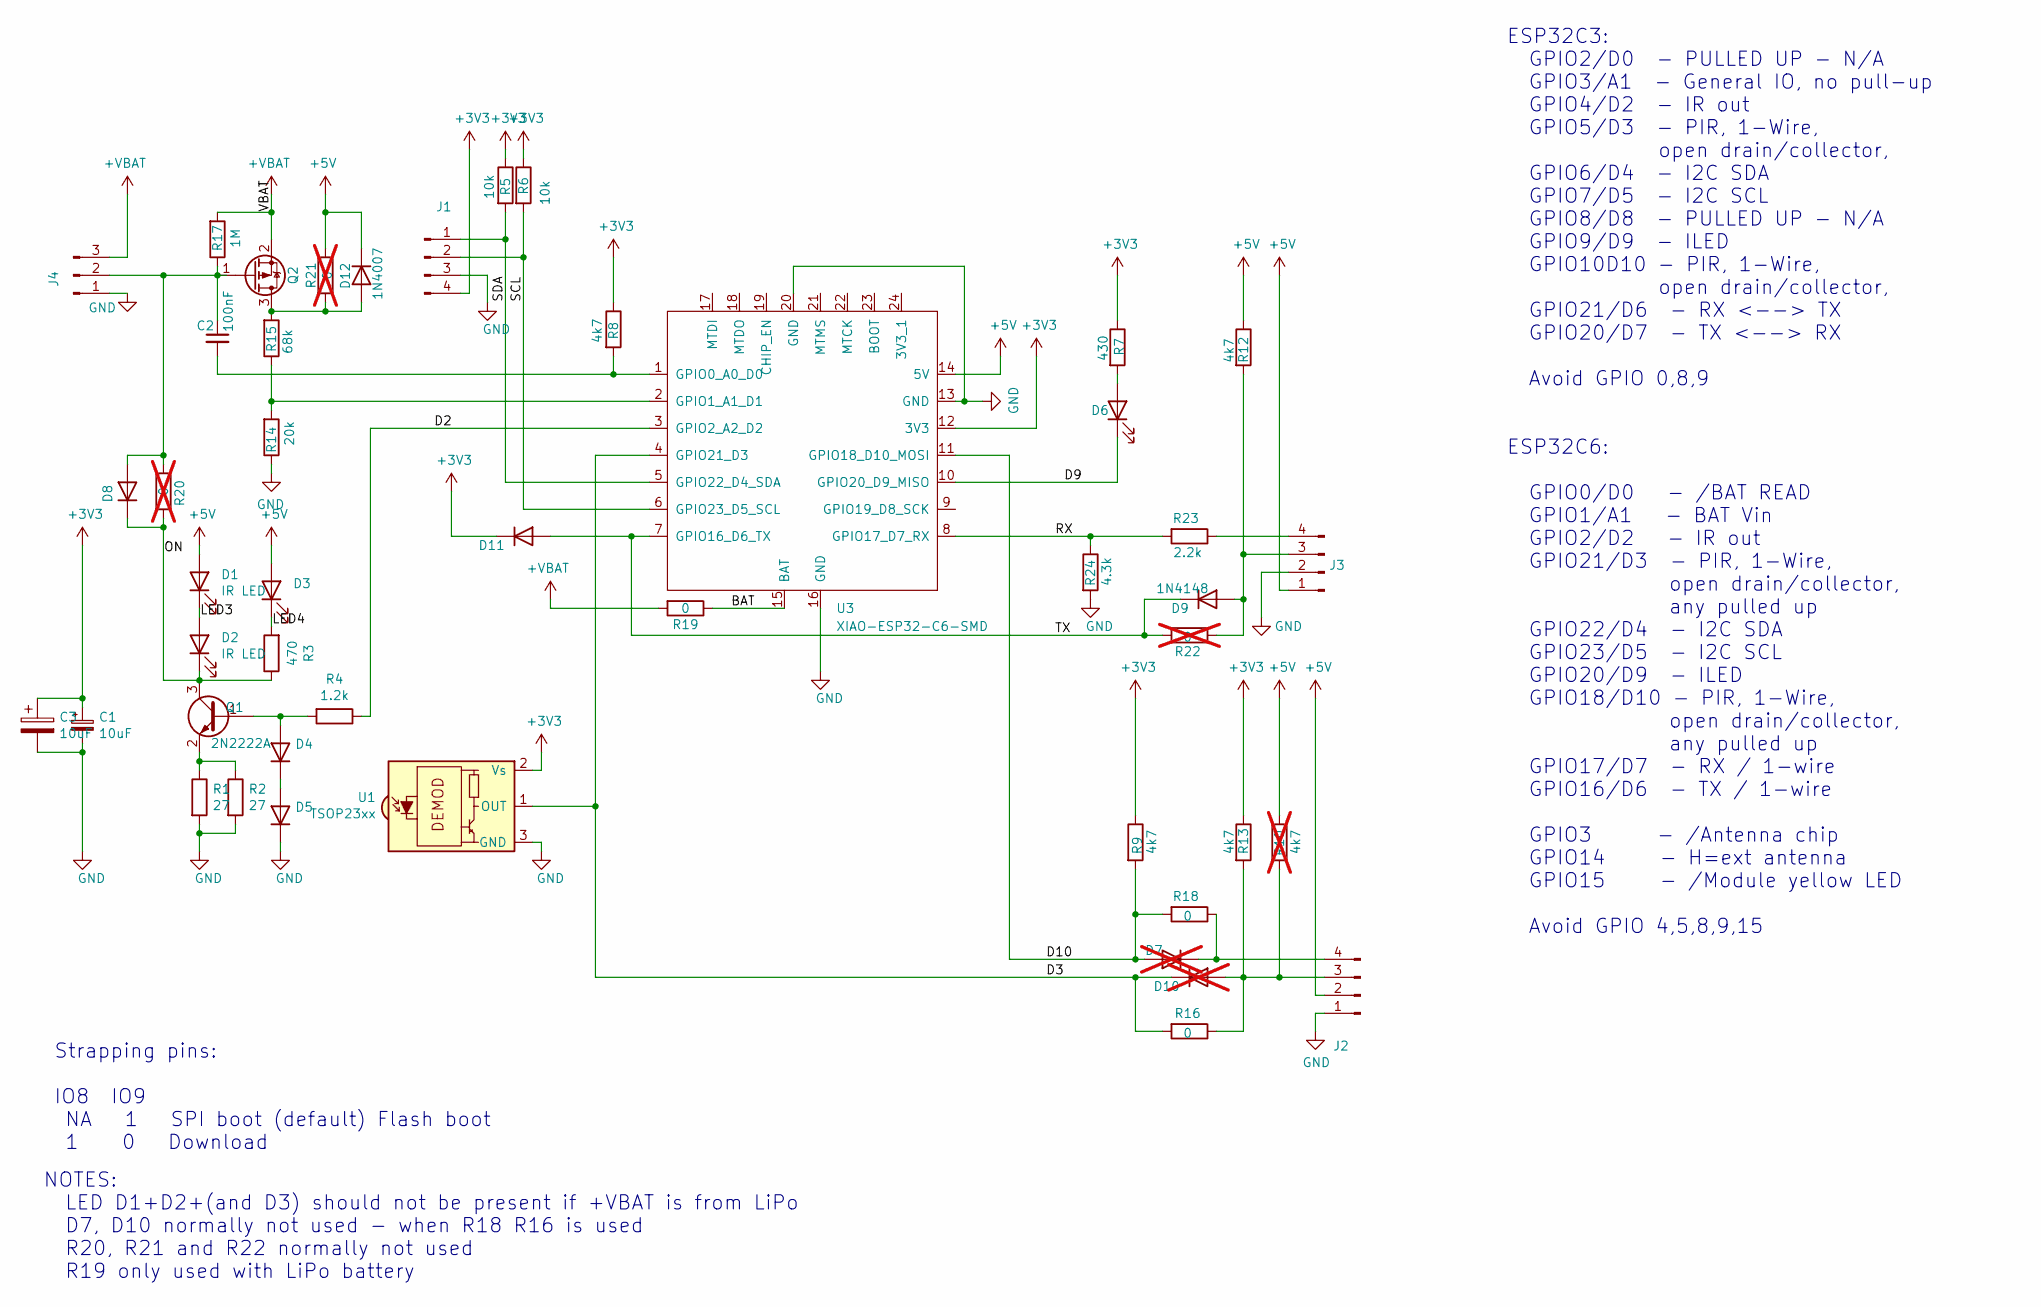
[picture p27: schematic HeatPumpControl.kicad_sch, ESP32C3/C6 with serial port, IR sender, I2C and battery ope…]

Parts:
C1: 10uF; CP_Radial_D5.0mm_P2.50mm
C2: 100nF; C_0805_2012Metric_Pad1.18x1.45mm_HandSolder
C3: 10uF; C_1206_3216Metric_Pad1.33x1.80mm_HandSolder
D1, D2: IR LED; LED_D5.0mm_Clear
D3, D6: LED_0805_2012Metric
D4, D5, D8, D11: 1N4148; D_SOD-323
D7: 1N4148; D_SOD-323; not fitted
D9: 1N4148; D_MiniMELF
D10: 1N4148; D_MiniMELF; not fitted
D12: 1N4007; D_SOD-123
J1, J2, J3: Conn_01x04_Male; PinHeader_1x04_P2.54mm_Vertical
J4: Conn_01x03_Male; PinHeader_1x03_P2.54mm_Vertical
Q1: 2N2222A; SOT-23_Handsoldering
Q2: Q_PMOS_GDS; SOT-23_Handsoldering
R1, R2: 27; R_0805_2012Metric
R3: 470; R_0805_2012Metric
R4: 1.2k; R_0805_2012Metric
R5, R6: 10k; R_0805_2012Metric
R7: 430; R_0805_2012Metric
R8, R9, R12, R13: 4k7; R_0805_2012Metric
R10: 4k7; R_0805_2012Metric; not fitted
R14: 20k; R_0805_2012Metric_Pad1.20x1.40mm_HandSolder
R15: 68k; R_0805_2012Metric_Pad1.20x1.40mm_HandSolder
R16, R18, R19: 0; R_0805_2012Metric
R17: 1M; R_0805_2012Metric_Pad1.20x1.40mm_HandSolder
R20, R21, R22: 0; R_0805_2012Metric; not fitted
R23: 2.2k; R_0805_2012Metric
R24: 4.3k; R_0805_2012Metric
U1: TSOP23xx; Vishay_MOLD-3Pin
U3: XIAO-ESP32-C6-SMD; XIAO-ESP32-C3C6-SMD

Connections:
+3V3: C1.1, C3.1, D11.1 (K), J1.4, R5.1, R6.1, R7.1, R8.1, R9.1, R13.1, U1.2 (Vs), U3.12 (3V3)
+5V: D1.2 (A), D3.2 (A), D12.1 (K), J2.2, J3.1, R10.1, R12.1, R21.1, U3.14 (5V)
+VBAT: J4.3, Q2.2 (S), R17.2, R19.2
/BAT: R19.1, U3.15 (BAT)
/D2: R4.1, U3.3 (GPIO2_A2_D2)
/D3: D10.1 (K), R16.2, U1.1 (OUT), U3.4 (GPIO21_D3)
/D9: D6.1 (K), U3.10 (GPIO20_D9_MISO)
/D10: D7.2 (A), R9.2, R18.2, U3.11 (GPIO18_D10_MOSI)
/LED3: D1.1 (K), D2.2 (A)
/LED4: D3.1 (K), R3.2
/ON: D2.1 (K), D8.1 (K), Q1.3 (C), R3.1, R20.2
/RX: R23.2, R24.1, U3.8 (GPIO17_D7_RX)
/SCL: J1.2, R6.2, U3.6 (GPIO23_D5_SCL)
/SDA: J1.1, R5.2, U3.5 (GPIO22_D4_SDA)
/TX: D9.1 (K), D11.2 (A), R22.2, U3.7 (GPIO16_D6_TX)
GND: C1.2, C3.2, D5.1 (K), J1.3, J2.1, J3.2, J4.1, R1.2, R2.2, R14.1, R24.2, U1.3 (GND), U3.13 (GND), U3.16 (GND), U3.20 (GND)
unnamed: D4.2 (A), Q1.1 (B), R4.2
unnamed: D4.1 (K), D5.2 (A)
unnamed: D6.2 (A), R7.2
unnamed: D7.1 (K), J2.4, R18.1
unnamed: C2.1, D8.2 (A), J4.2, Q2.1 (G), R17.1, R20.1
unnamed: D9.2 (A), J3.3, R12.2, R22.1
unnamed: D10.2 (A), J2.3, R10.2, R13.2, R16.1
unnamed: D12.2 (A), Q2.3 (D), R15.2, R21.2
unnamed: J3.4, R23.1
unnamed: Q1.2 (E), R1.1, R2.1
unnamed: C2.2, R8.2, U3.1 (GPIO0_A0_D0)
unnamed: R14.2, R15.1, U3.2 (GPIO1_A1_D1)

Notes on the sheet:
Strapping pins: IO8 IO9 NA 1 SPI boot (default) Flash boot 1 0 Download
NOTES: LED D1+D2+(and D3) should not be present if +VBAT is from LiPo D7, D10 normally not used - when R18 R16 is used R20, R21 and R22 normally not used R19 only used with LiPo battery
ESP32C3: GPIO2/D0 - PULLED UP - N/A GPIO3/A1 - General IO, no pull-up GPIO4/D2 - IR out GPIO5/D3 - PIR, 1-Wire, open drain/collector, GPIO6/D4 - I2C SDA GPIO7/D5 - I2C SCL GPIO8/D8 - PULLED UP - N/A GPIO9/D9 - ILED GPIO10D10 - PIR, 1-Wire, open drain/collector, GPIO21/D6 - RX <--> TX GPIO20/D7 - TX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

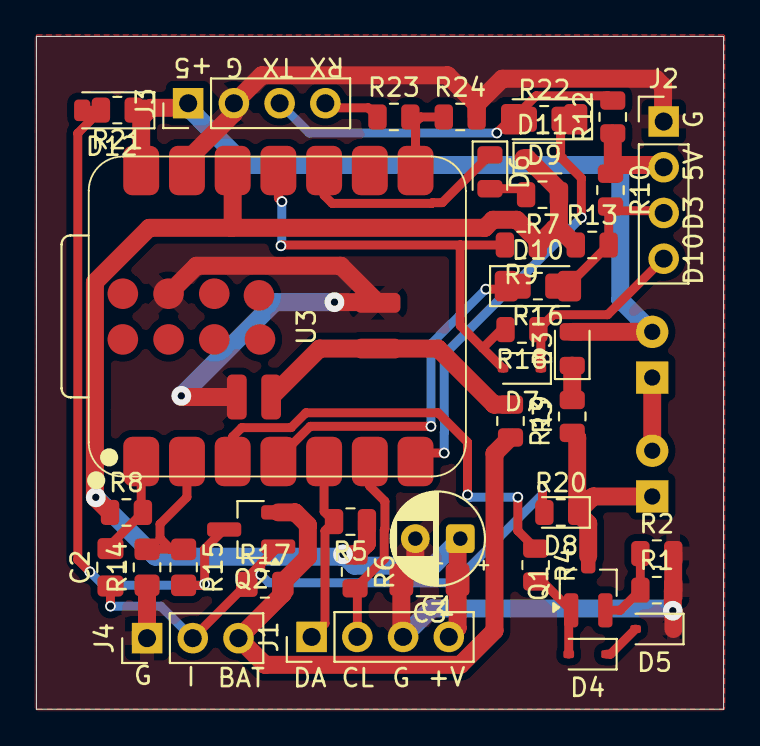
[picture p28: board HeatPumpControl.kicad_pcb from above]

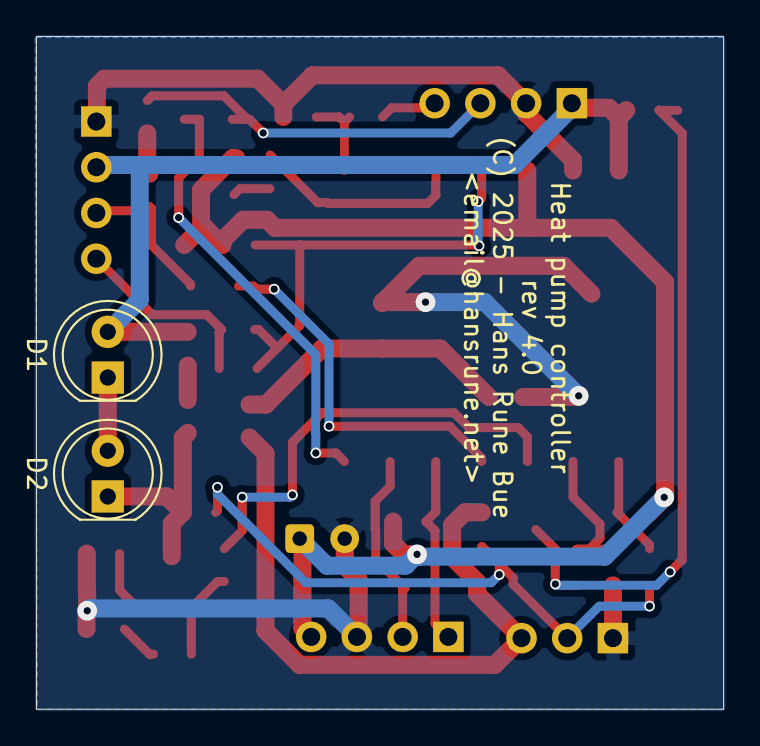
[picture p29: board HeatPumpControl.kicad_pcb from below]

Board: 2 copper layers, 38.2 x 37.4 mm, 45 parts (2 on the bottom side), 28 nets.

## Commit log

2024-06-20 Initial commits
    [HeatPumpControl.kicad_pcb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]
2024-06-20 Renamed pdf print files
2024-06-24 Fixed Q1 pinout and grounding fills
    [HeatPumpControl.kicad_pcb, HeatPumpControl.kicad_sch]
2024-06-24 New pdf prints
2024-06-24 v2.0.1 KiCAD changes
    [HeatPumpControl.kicad_pcb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]
2024-09-03 3D printer enclosure added
    [HeatPumpControl-Body.stl, HeatPumpControl-Lid.stl, HeatPumpControl.FCStd]
2024-09-04 Add note on 3D enclosure
2024-09-19 New 3D model
    [HeatPumpControl.kicad_pcb]
2025-10-15 ESP32C6 support
    [HeatPumpControl.kicad_pcb, HeatPumpControl.kicad_sch]
2025-10-20 Diode foorptint changes
    [HeatPumpControl.kicad_pcb]
2025-10-21 Add 5-3.3 V divider for Rx
    [HeatPumpControl.kicad_pcb, HeatPumpControl.kicad_sch]
2025-10-26 Added combined C3/C6 module footprint
    [HeatPumpControl.kicad_pcb, HeatPumpControl.kicad_sch]
2025-10-28 Manufacturing for v4.0
    [HeatPumpControl.kicad_pcb, HeatPumpControl.kicad_sch]
2025-12-01 Add GPIO descriptions and other texts
    [HeatPumpControl.kicad_pcb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]
2025-12-04 Update FreeCAD case for v4.x
    [HeatPumpControl-Body-4.stl, HeatPumpControl-Lid-4.stl, HeatPumpControl.FCStd]
2025-12-04 Add diode for VBAT -> 5V
    [HeatPumpControl.kicad_pcb, HeatPumpControl.kicad_sch]
2025-12-23 Change to SOD-123 for 1N4007
    [HeatPumpControl.kicad_pcb, HeatPumpControl.kicad_sch]
2025-12-25 Prints, Gerber and BOM for v4.0.3
2025-12-25 Gerber zip file renamed
2025-12-25 Missing Gerber file
2026-01-05 Fill zones updated
    [HeatPumpControl.kicad_pcb]
2026-09-01 DRC changes
    [HeatPumpControl.kicad_pcb, HeatPumpControl.kicad_sch]

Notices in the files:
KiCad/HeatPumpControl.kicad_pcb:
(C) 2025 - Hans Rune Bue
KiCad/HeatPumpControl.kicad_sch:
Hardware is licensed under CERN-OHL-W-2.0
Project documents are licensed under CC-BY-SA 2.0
